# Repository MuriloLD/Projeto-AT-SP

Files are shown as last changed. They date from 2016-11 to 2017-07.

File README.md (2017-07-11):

# Projeto-AT-SP
Source code and instructions needed for constructing AntTruck and SuperTruck. Both mobile robots conected to Internet.

For more information please download the documentation [here](https://github.com/MuriloLD/Projeto-AT-SP/blob/master/Documenta%C3%A7%C3%A3o_Projeto_ATSP.pdf).

robots

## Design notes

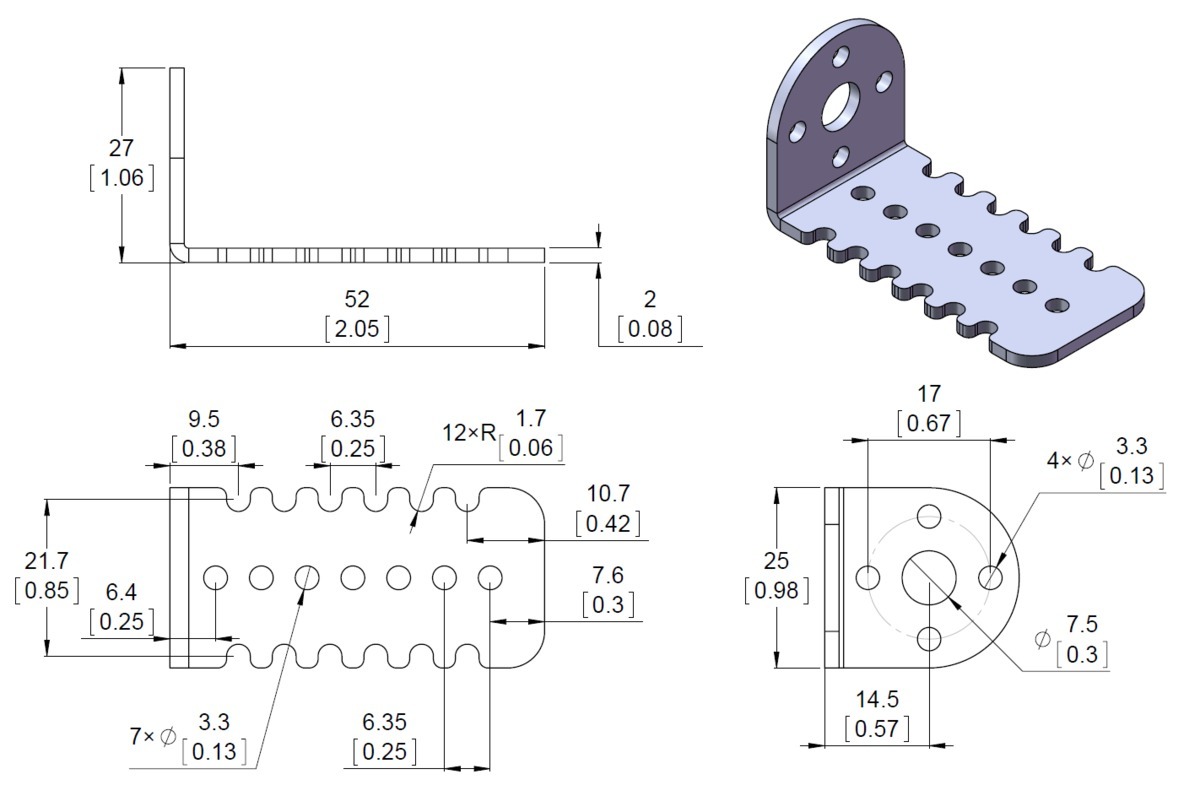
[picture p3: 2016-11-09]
Peças 3D/suporte_motor_v3/GearMotor Bracket .jpg

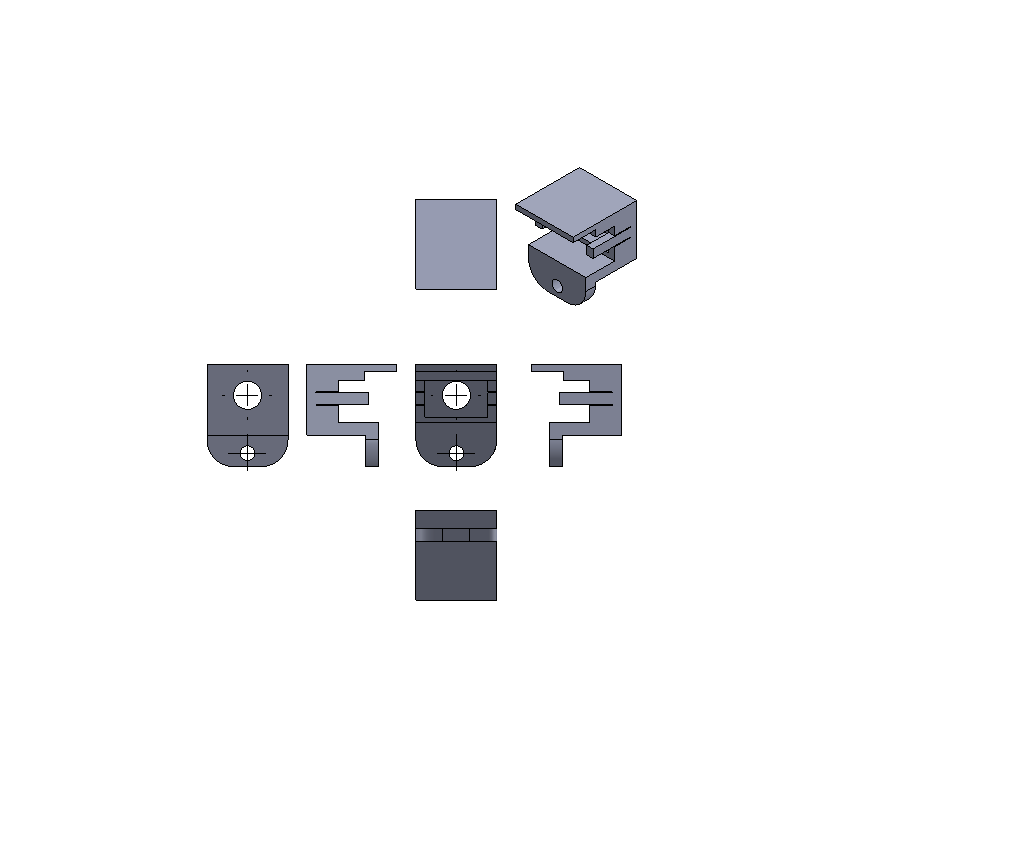
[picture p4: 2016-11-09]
Peças 3D/chave_On_Off/Top/vistas_chaveOnOff_top.PNG

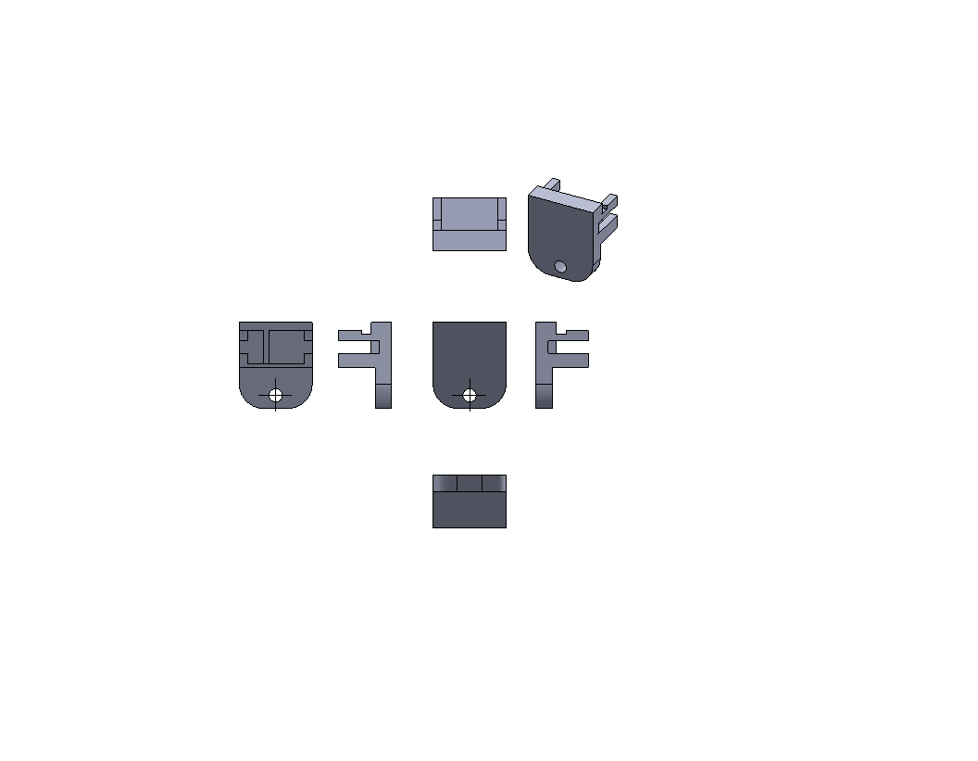
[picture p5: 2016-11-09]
Peças 3D/chave_On_Off/Bot/vistas.PNG

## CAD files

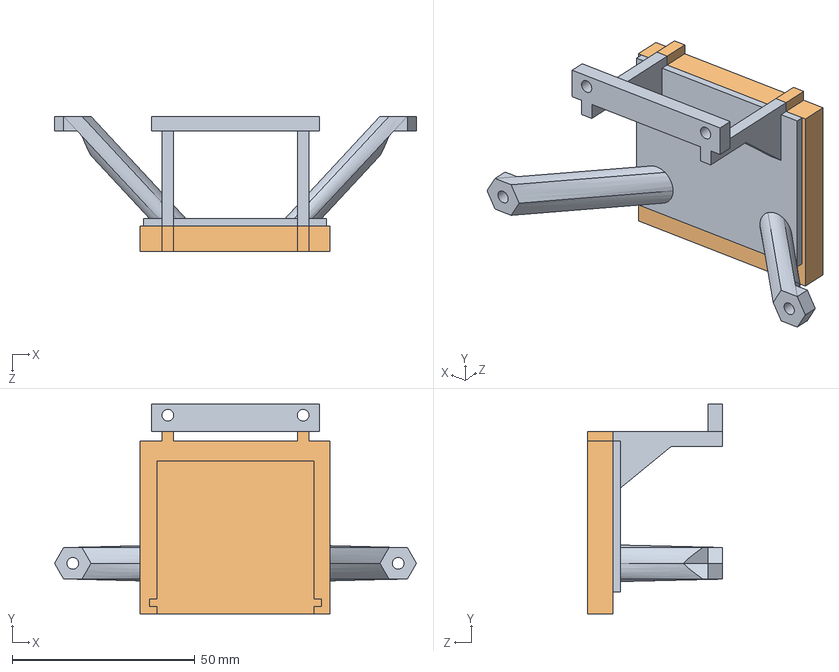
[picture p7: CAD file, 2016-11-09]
Peças 3D/suporte_ESP8266/Montagem1.SLDASM
99.0 x 57.3 x 37.0 mm
Suporte_ESP8266_v4 - P1
Suporte_ESP8266_v4 - P2

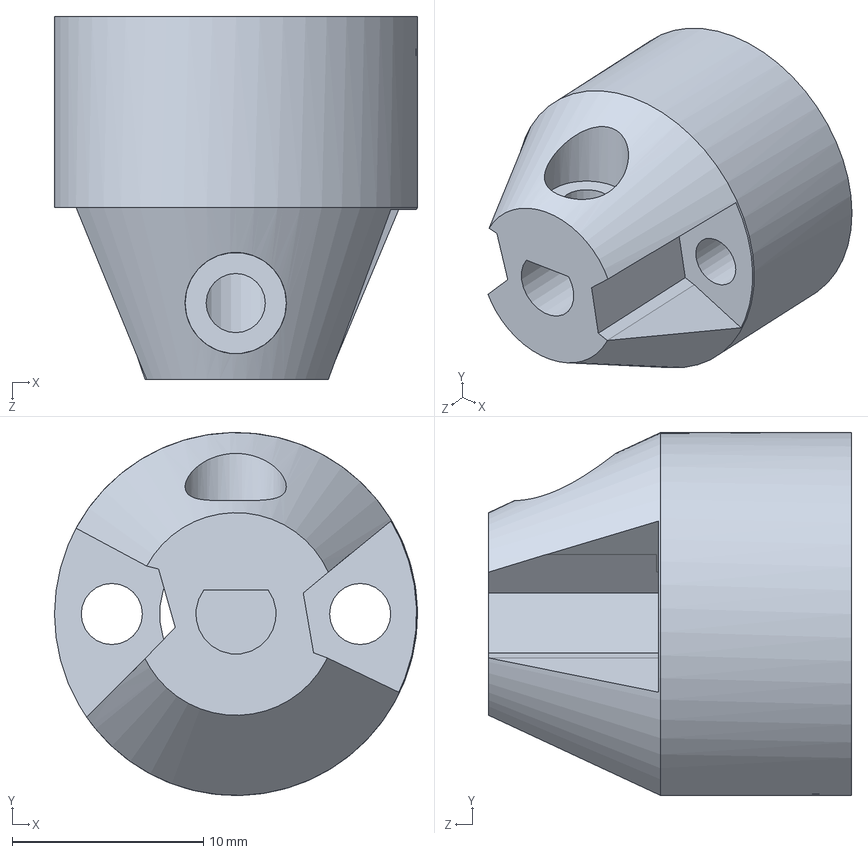
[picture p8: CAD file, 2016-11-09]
Peças 3D/adaptador_motor_v5/adaptador_motor_v5.SLDPRT
19.0 x 19.0 x 19.0 mm

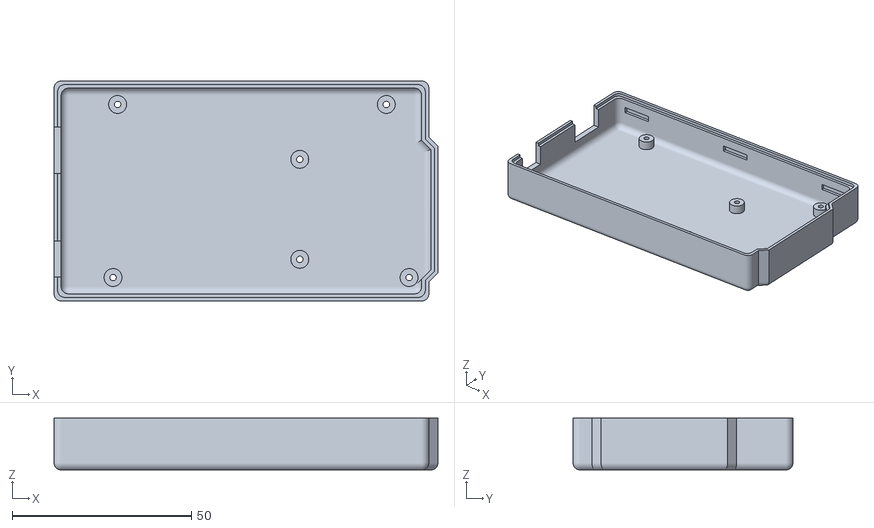
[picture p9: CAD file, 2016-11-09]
Peças 3D/case_arduino_mega_stl/arduino_mega_bottom.stl
107.1 x 61.3 x 14.5

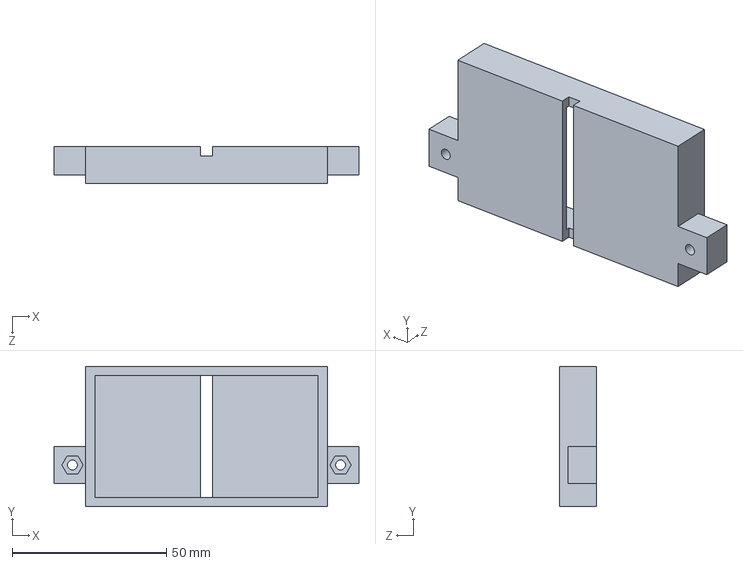
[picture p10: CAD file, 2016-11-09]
Peças 3D/case_bateria/Bot/SuporteBateria_BOT.SLDPRT
99.0 x 45.5 x 12.0 mm

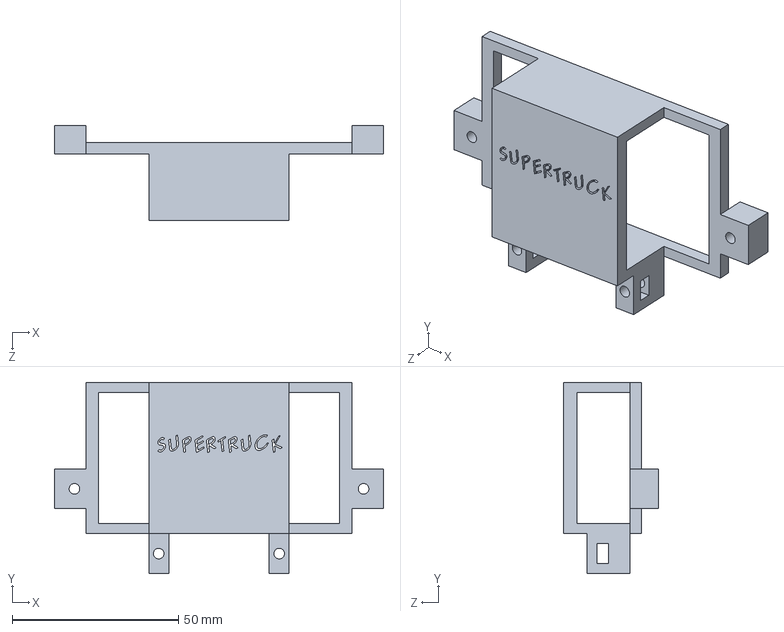
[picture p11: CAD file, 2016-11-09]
Peças 3D/case_bateria/Top/SuporteBateria_TOP.SLDPRT
99.0 x 57.5 x 28.5 mm

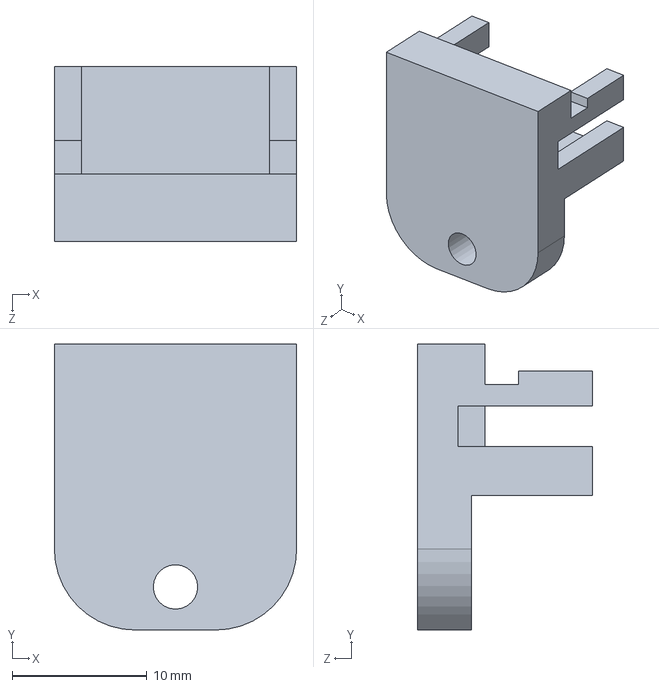
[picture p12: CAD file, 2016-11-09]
Peças 3D/chave_On_Off/Bot/Chave_v1.SLDPRT
18.0 x 21.2 x 13.0 mm

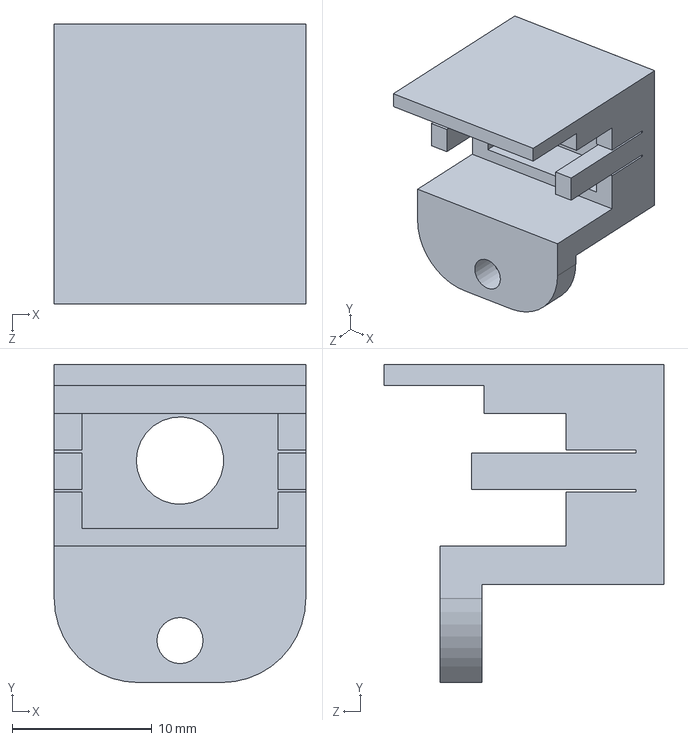
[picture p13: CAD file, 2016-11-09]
Peças 3D/chave_On_Off/Top/Chave_v2.SLDPRT
18.0 x 22.8 x 20.0 mm

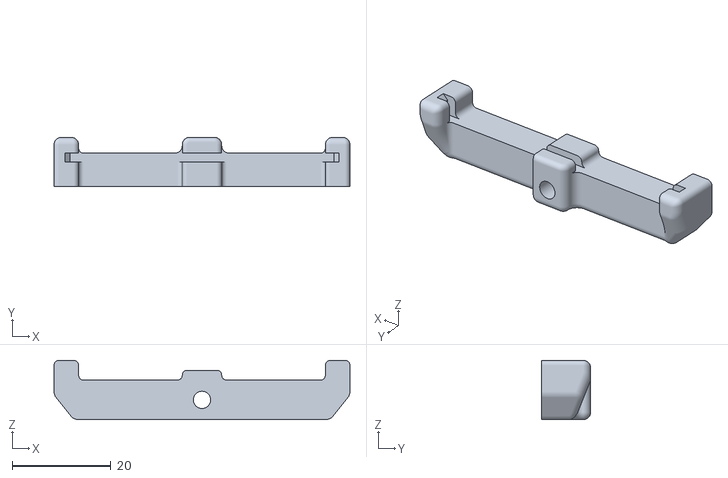
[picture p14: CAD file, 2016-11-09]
Peças 3D/suporte_arduino_mega_stl/Support carte AV Arduino.stl
60.0 x 10.0 x 12.0

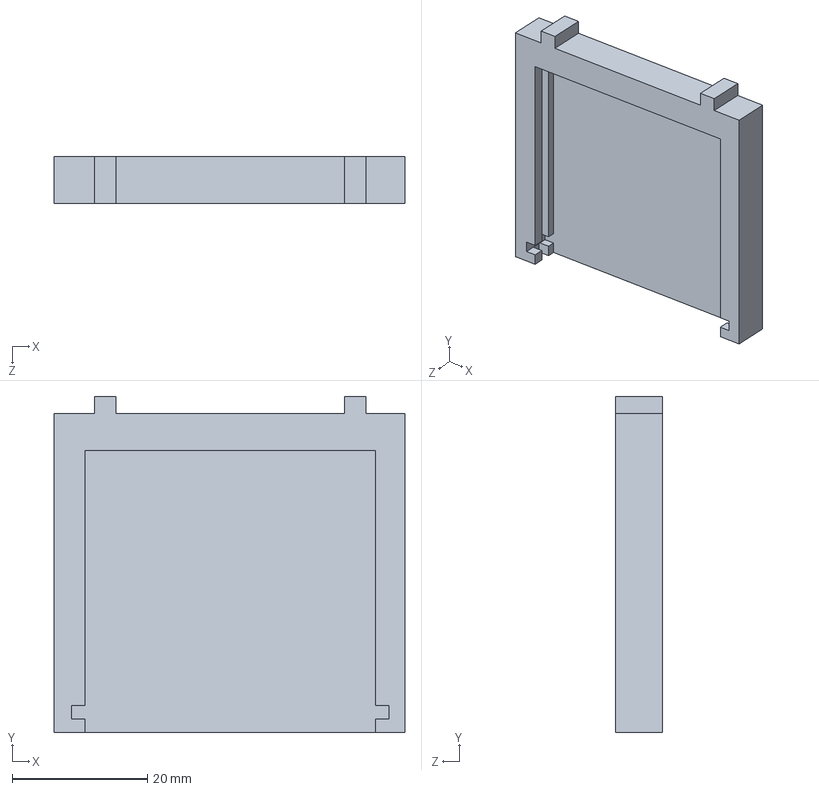
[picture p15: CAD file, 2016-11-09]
Peças 3D/suporte_ESP8266/Suporte_ESP8266_v4 - P2.SLDPRT
52.0 x 49.8 x 7.00 mm

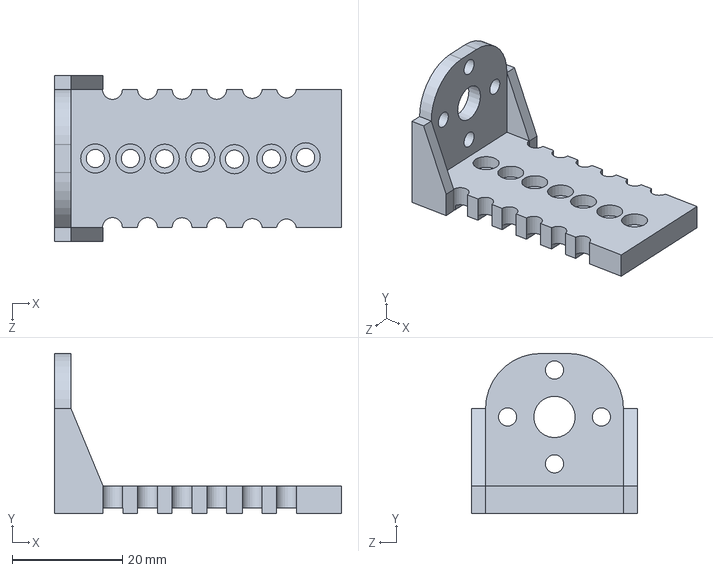
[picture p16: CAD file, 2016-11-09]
Peças 3D/suporte_motor_v3/suporte motor_v3.SLDPRT
52.0 x 29.0 x 30.0 mm

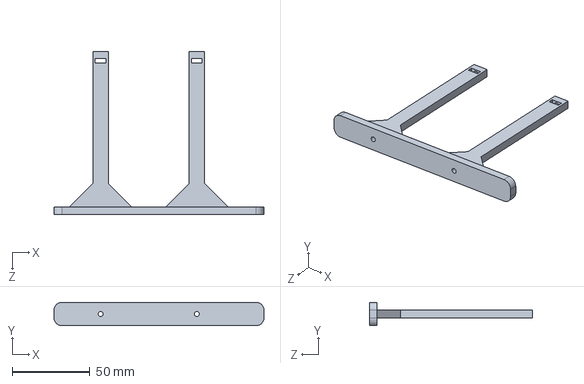
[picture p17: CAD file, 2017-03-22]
Peças 3D/suporte_padrao/suporte_padrao.SLDPRT
135.0 x 15.0 x 105.0 mm

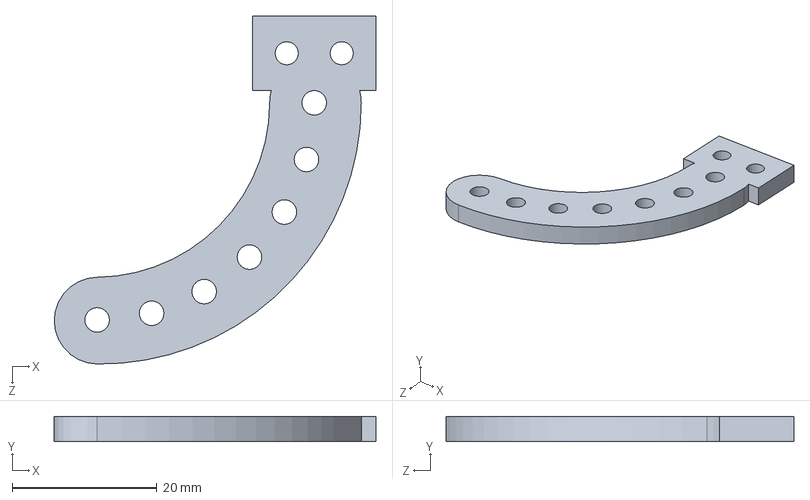
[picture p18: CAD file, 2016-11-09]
Peças 3D/suporte_ultrassom/US_guia/us_guia.SLDPRT
44.4 x 3.50 x 48.1 mm

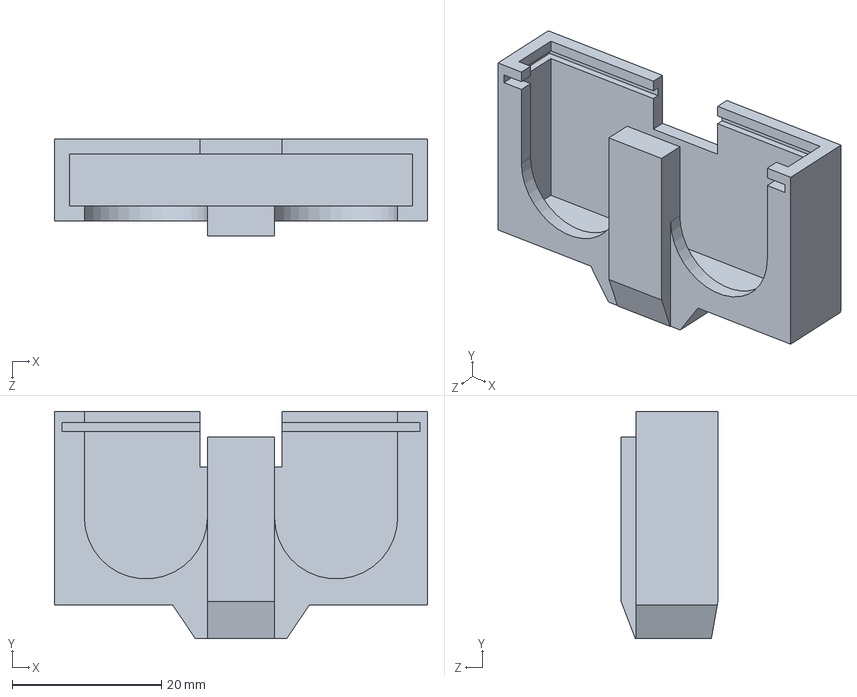
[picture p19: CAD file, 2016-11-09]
Peças 3D/suporte_ultrassom/US_Servo/ultrassom - SERVO.SLDPRT
50.0 x 30.4 x 13.0 mm

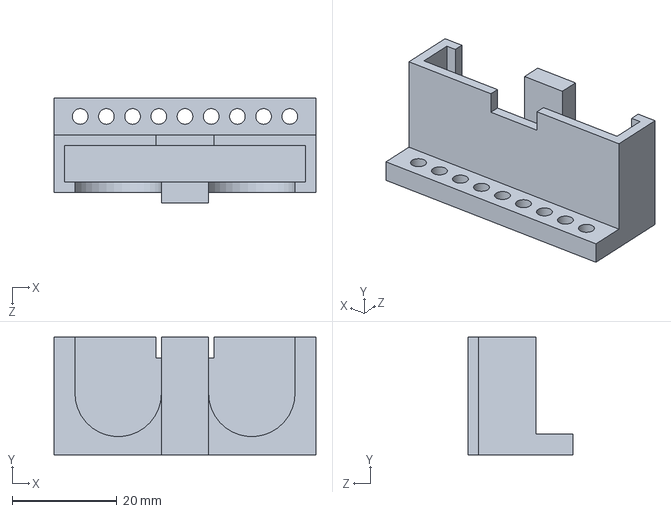
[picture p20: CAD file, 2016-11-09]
Peças 3D/suporte_ultrassom/US_simples/ultrassom.SLDPRT
50.0 x 22.5 x 20.0 mm

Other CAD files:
Peças 3D/case_arduino_mega_stl/arduino_mega_top.stl
Peças 3D/suporte_arduino_mega_stl/Support carte AR Arduino.stl
Peças 3D/suporte_ESP8266/Suporte_ESP8266_v4 - P3.SLDPRT
Peças 3D/suporte_ESP8266/Montagem1 - Suporte_ESP8266_v4 - P2-1.STL
Peças 3D/adaptador_motor_v5/Template_cotas.SLDDRW
Peças 3D/adaptador_motor_v5/adaptador_motor_v5.STL
Peças 3D/adaptador_motor_v5/template_vistas.SLDDRW
Peças 3D/case_bateria/Bot/SuporteBateria_BOT.STL
Peças 3D/case_bateria/Bot/Template_cotas.SLDDRW
Peças 3D/case_bateria/Bot/template_vistas.SLDDRW
Peças 3D/case_bateria/Top/SuporteBateria_TOP.STL
Peças 3D/case_bateria/Top/Template_cotas.SLDDRW
Peças 3D/case_bateria/Top/template_vistas.SLDDRW
Peças 3D/chave_On_Off/Bot/Chave_v1.STL
Peças 3D/chave_On_Off/Bot/Template_cotas.SLDDRW
Peças 3D/chave_On_Off/Bot/template_vistas.SLDDRW
Peças 3D/chave_On_Off/Top/Chave_v2.STL
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

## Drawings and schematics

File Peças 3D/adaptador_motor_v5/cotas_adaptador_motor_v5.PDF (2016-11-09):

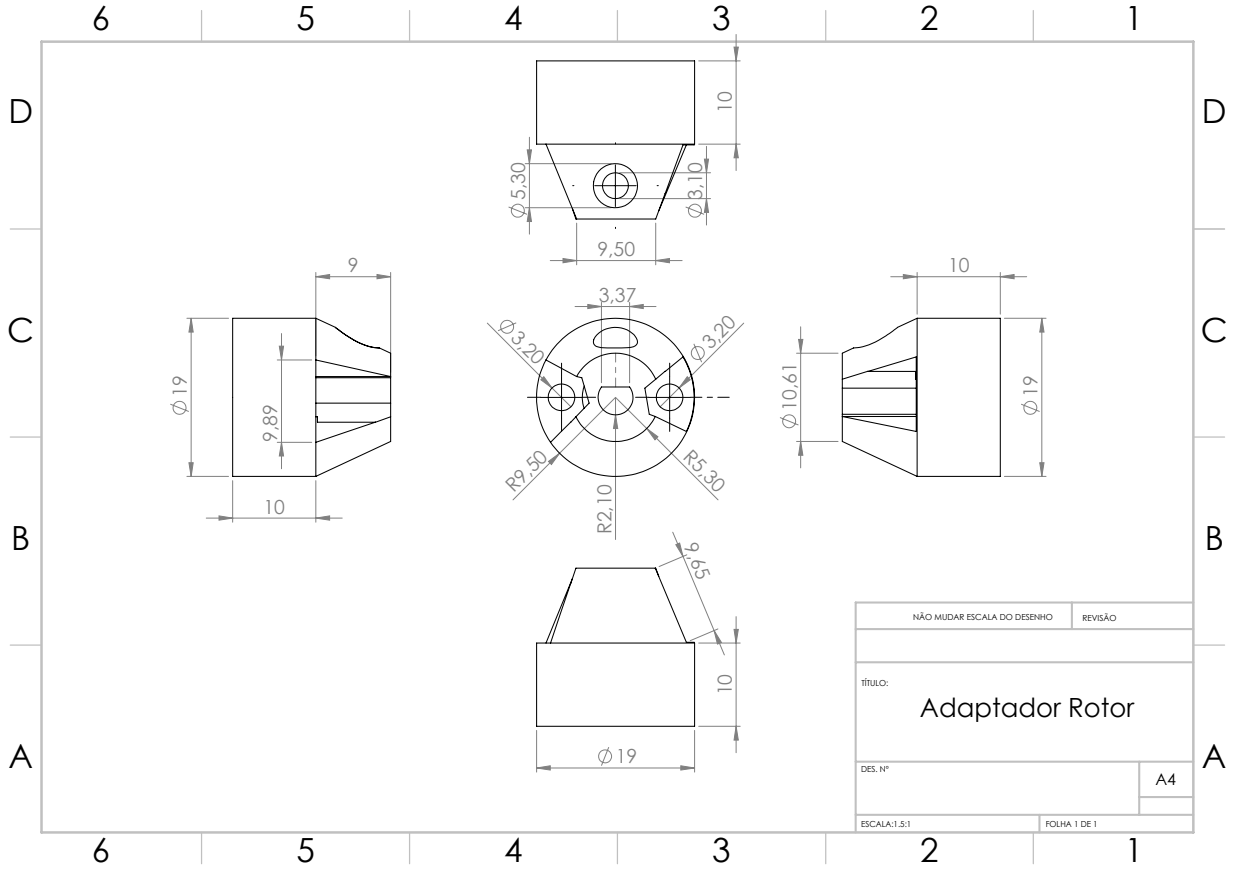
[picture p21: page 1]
NÃO MUDAR ESCALA DO DESENHO; REVISÃO; DES. Nº; ESCALA:1.5:1; FOLHA 1 DE 1; Adaptador Rotor

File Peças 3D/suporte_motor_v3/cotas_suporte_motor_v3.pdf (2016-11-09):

D

6 | 5 | 4 | 3 | 2 | 1

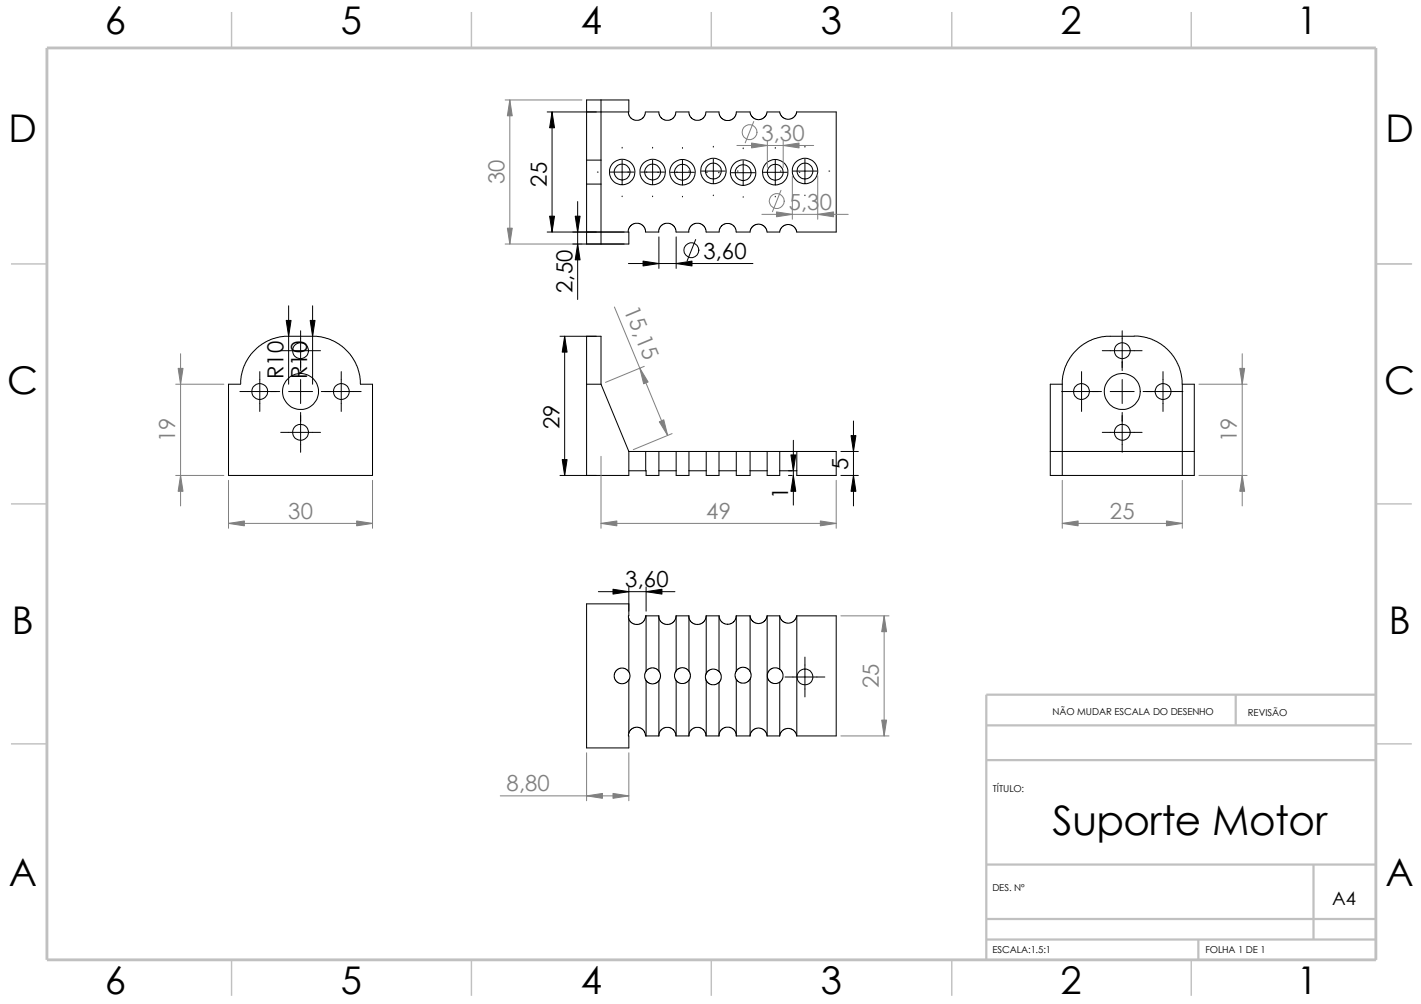
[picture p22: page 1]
NÃO MUDAR ESCALA DO DESENHO; REVISÃO; TÍTULO:; DES. Nº; ESCALA:1.5:1; FOLHA 1 DE 1; Suporte Motor

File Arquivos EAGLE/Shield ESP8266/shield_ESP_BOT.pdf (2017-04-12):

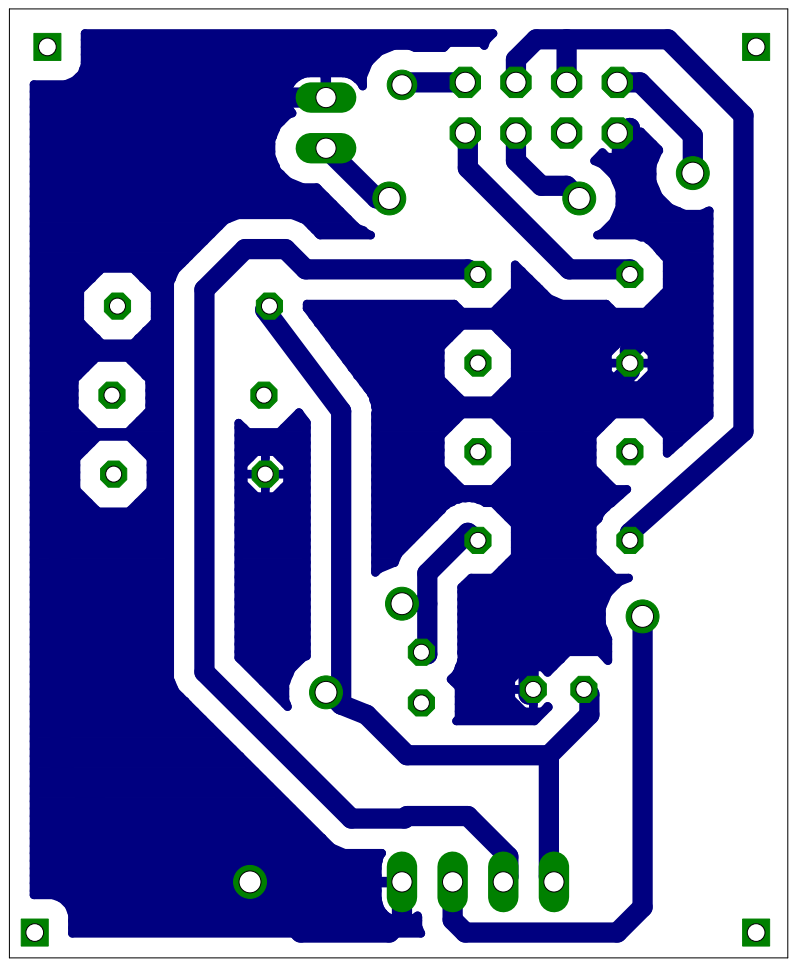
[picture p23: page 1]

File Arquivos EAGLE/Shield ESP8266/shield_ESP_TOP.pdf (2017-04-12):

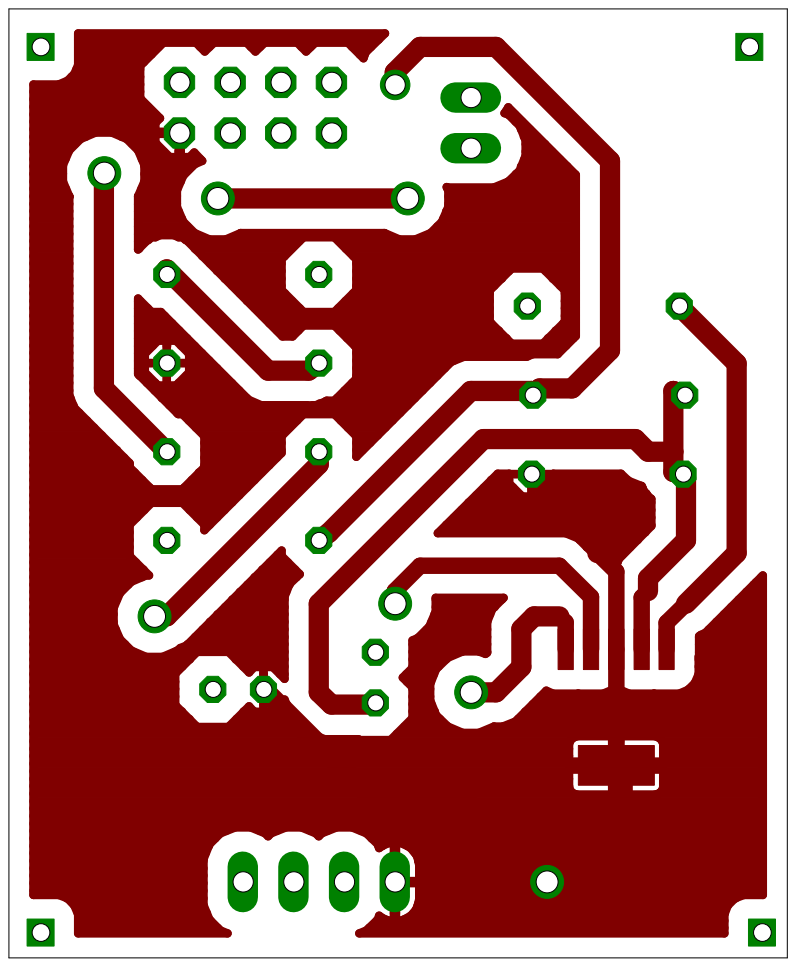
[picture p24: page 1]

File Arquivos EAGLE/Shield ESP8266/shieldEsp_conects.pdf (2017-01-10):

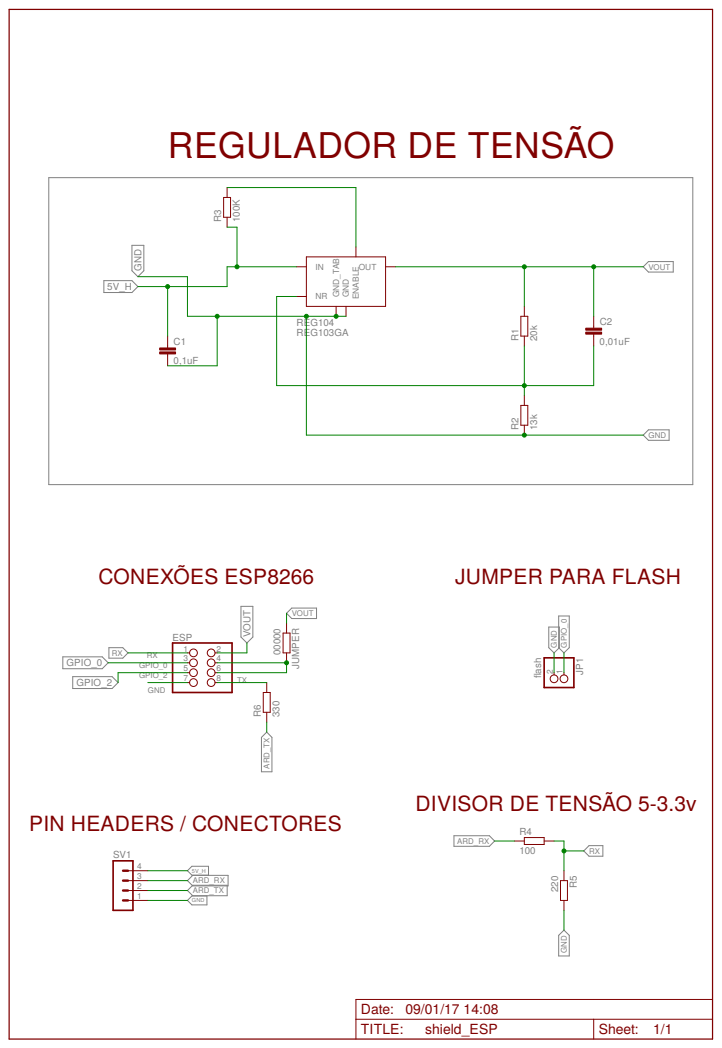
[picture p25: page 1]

5 6
7 8 | TX

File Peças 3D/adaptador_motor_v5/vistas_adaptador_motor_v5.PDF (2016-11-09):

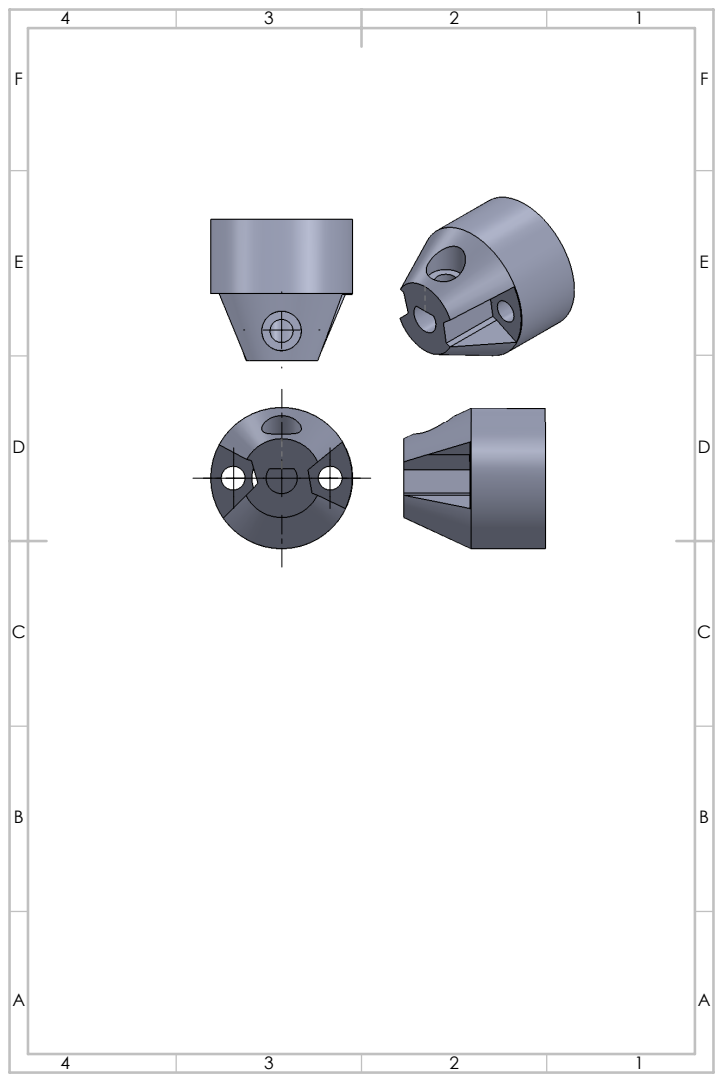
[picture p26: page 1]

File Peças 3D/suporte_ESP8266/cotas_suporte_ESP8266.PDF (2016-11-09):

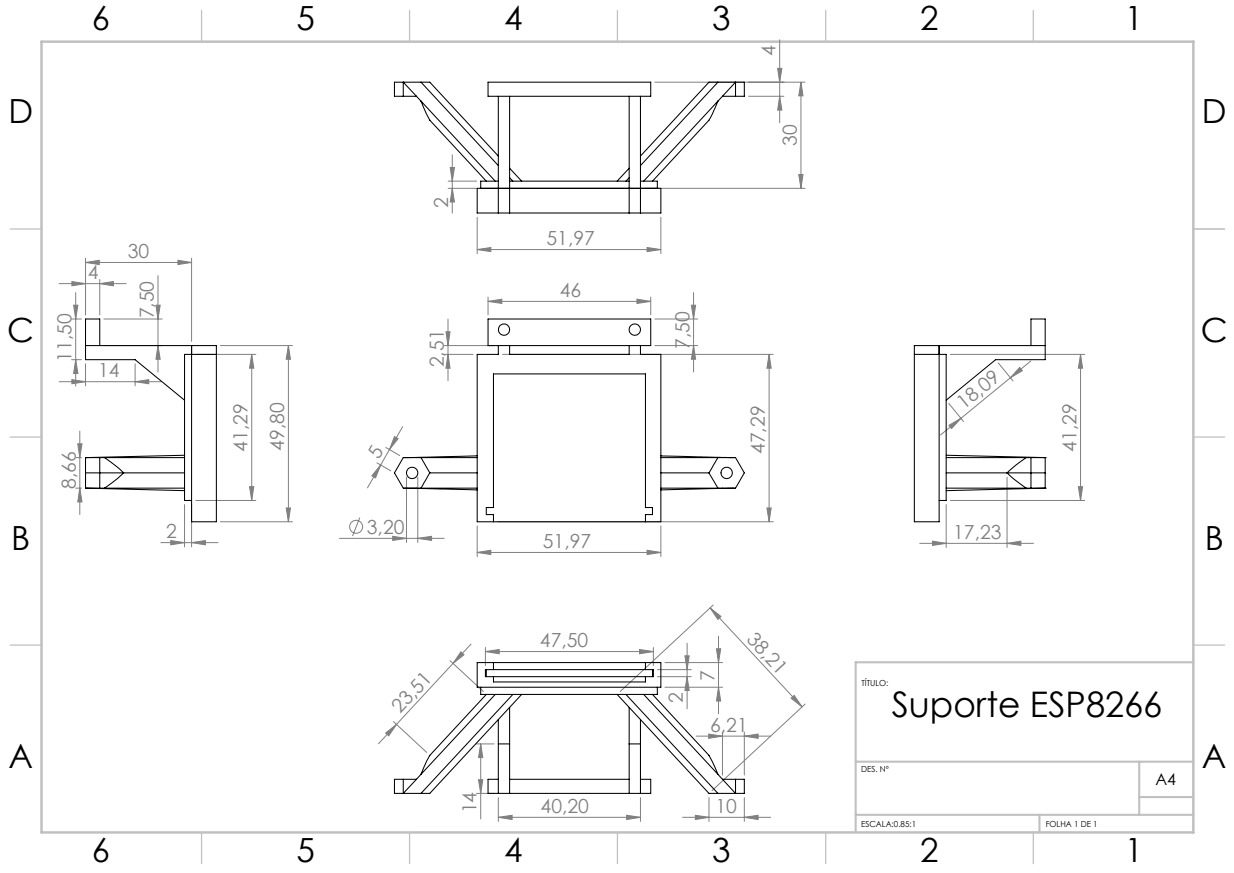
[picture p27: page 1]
DES. Nº; ESCALA:0.85:1; FOLHA 1 DE 1; Suporte ESP8266

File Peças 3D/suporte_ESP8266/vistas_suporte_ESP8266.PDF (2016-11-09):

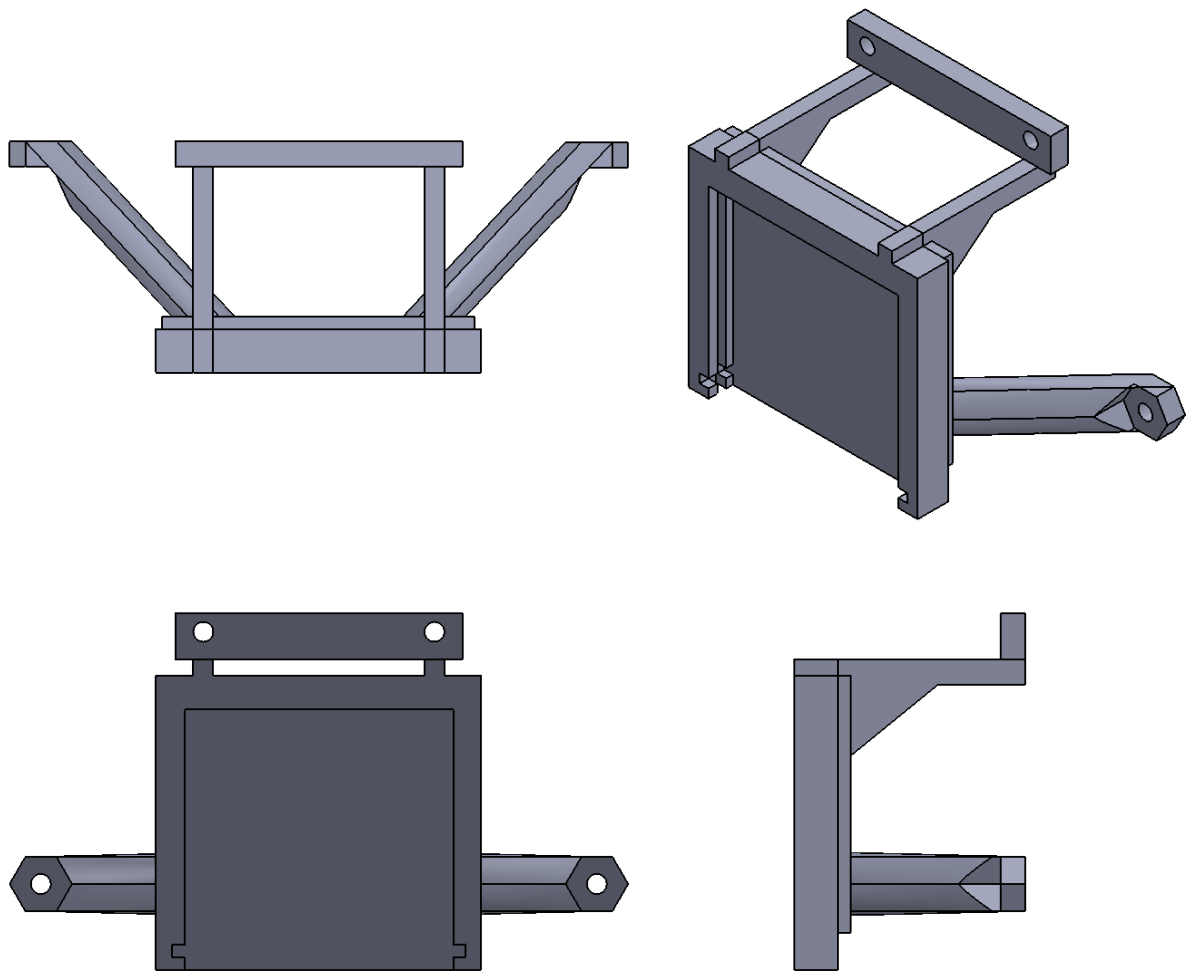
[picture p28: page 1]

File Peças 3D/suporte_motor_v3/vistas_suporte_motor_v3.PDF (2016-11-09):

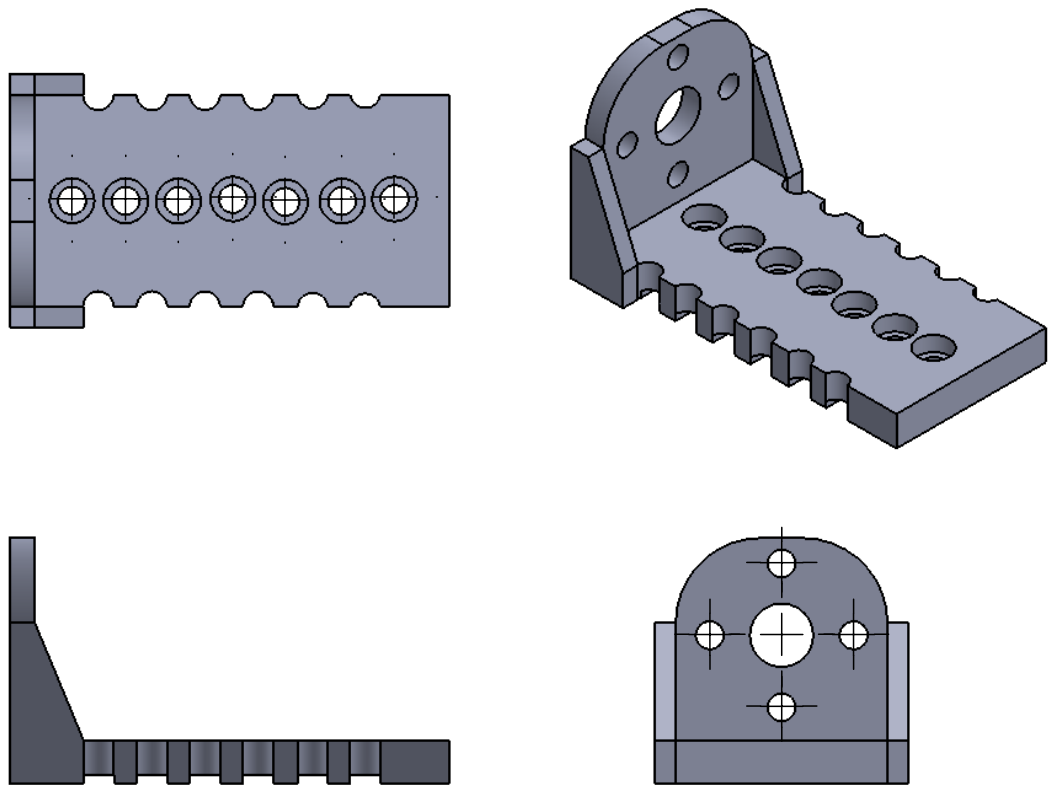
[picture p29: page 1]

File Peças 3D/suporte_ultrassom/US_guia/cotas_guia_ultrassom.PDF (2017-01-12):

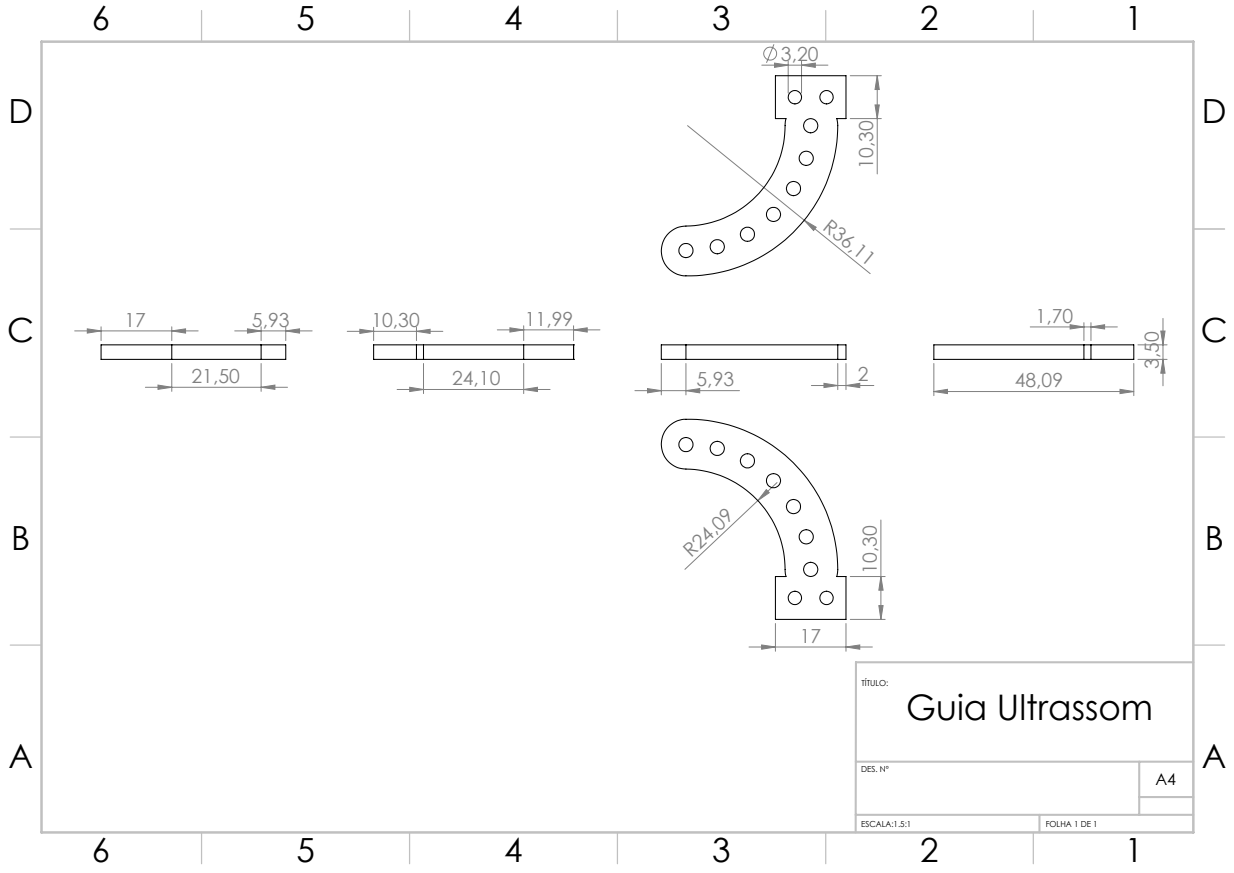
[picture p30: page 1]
DES. Nº; ESCALA:1.5:1; FOLHA 1 DE 1; Guia Ultrassom

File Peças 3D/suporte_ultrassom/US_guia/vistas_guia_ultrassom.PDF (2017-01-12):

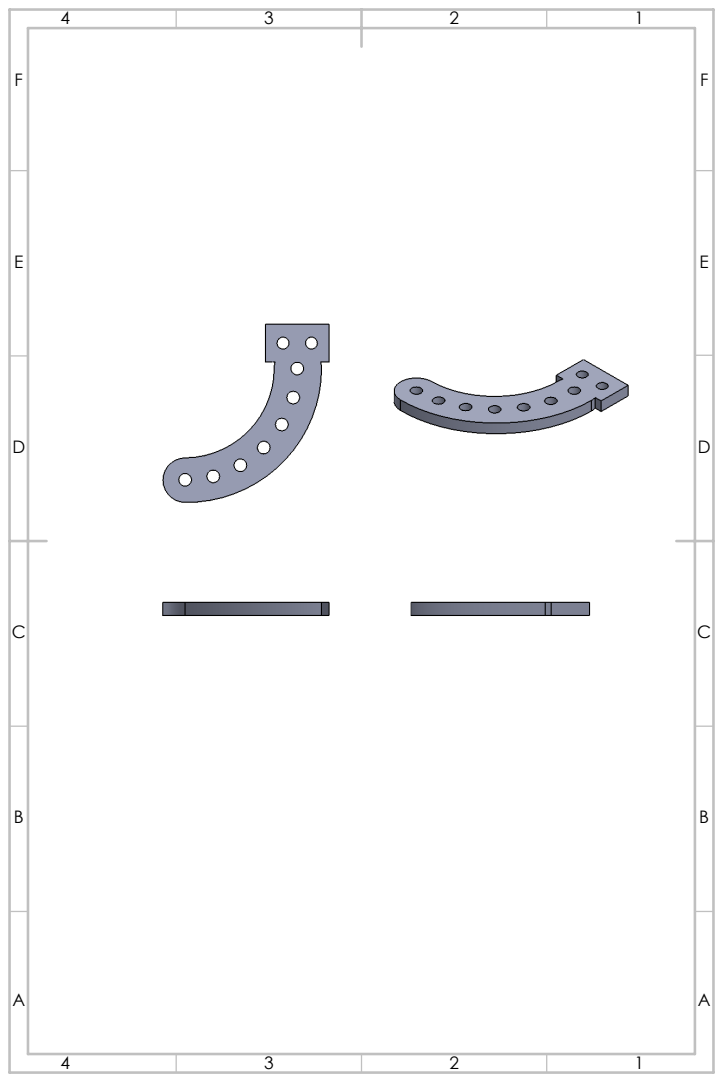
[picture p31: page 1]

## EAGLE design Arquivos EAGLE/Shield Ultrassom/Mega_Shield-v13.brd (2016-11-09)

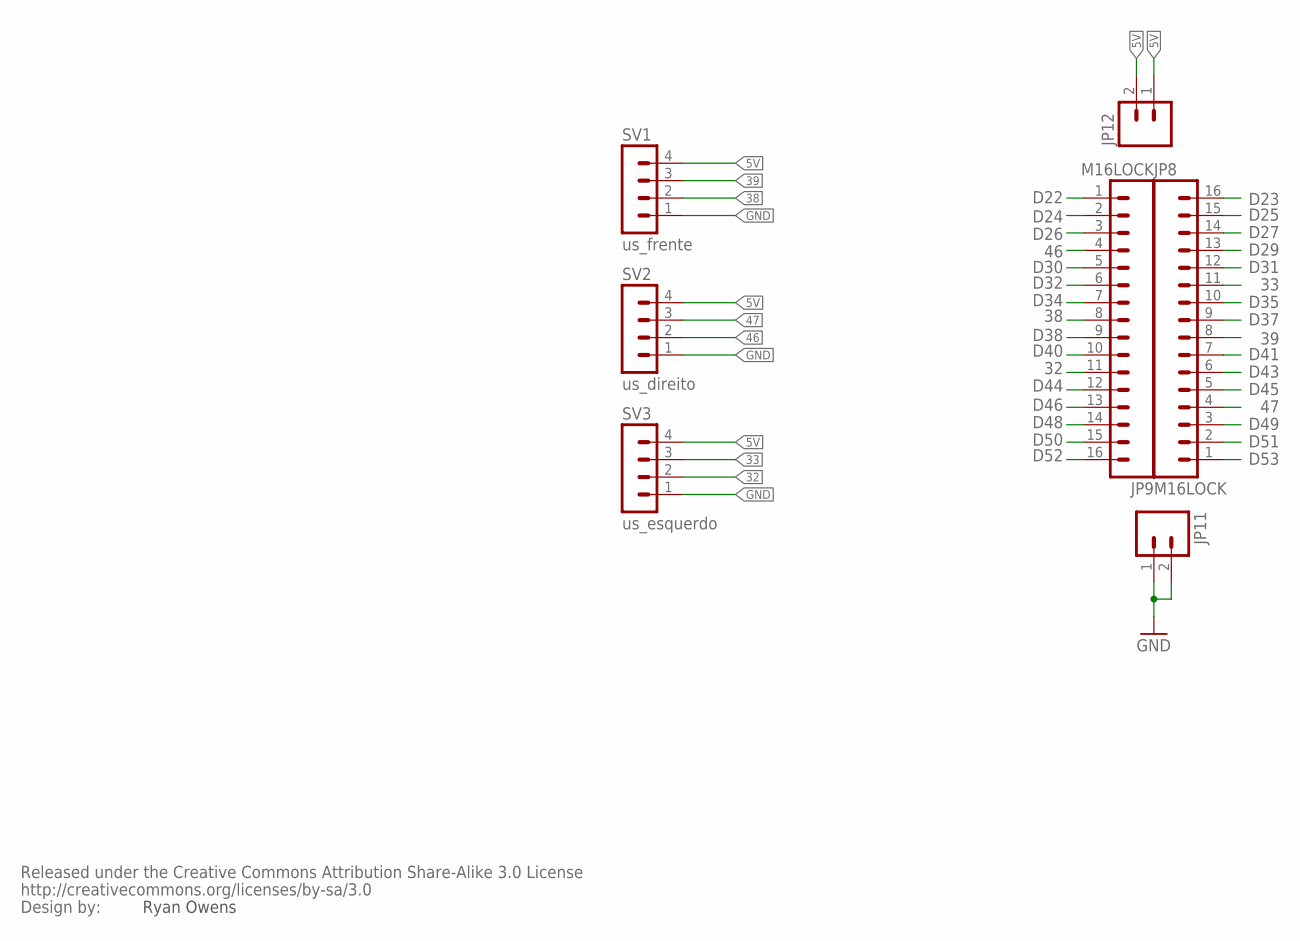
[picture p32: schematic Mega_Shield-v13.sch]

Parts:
JP8, JP9: M16LOCK; 1X16_LOCK
JP11, JP12: M02LOCK; 1X02_LOCK
SV1: us_frente; MA04-1
SV2: us_direito; MA04-1
SV3: us_esquerdo; MA04-1
U$2: CREATIVE_COMMONS

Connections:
5V: JP12.1, JP12.2, SV1.4, SV2.4, SV3.4
32: JP9.11, SV3.2
33: JP8.11, SV3.3
38: JP9.8, SV1.2
39: JP8.8, SV1.3
46: JP9.4, SV2.2
47: JP8.4, SV2.3
D22: JP9.1
D23: JP8.16
D24: JP9.2
D25: JP8.15
D26: JP9.3
D27: JP8.14
D29: JP8.13
D30: JP9.5
D31: JP8.12
D32: JP9.6
D34: JP9.7
D35: JP8.10
D37: JP8.9
D38: JP9.9
D40: JP9.10
D41: JP8.7
D43: JP8.6
D44: JP9.12
D45: JP8.5
D46: JP9.13
D48: JP9.14
D49: JP8.3
D50: JP9.15
D51: JP8.2
D52: JP9.16
D53: JP8.1
GND: JP11.1, JP11.2, SV1.1, SV2.1, SV3.1

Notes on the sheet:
Ryan Owens

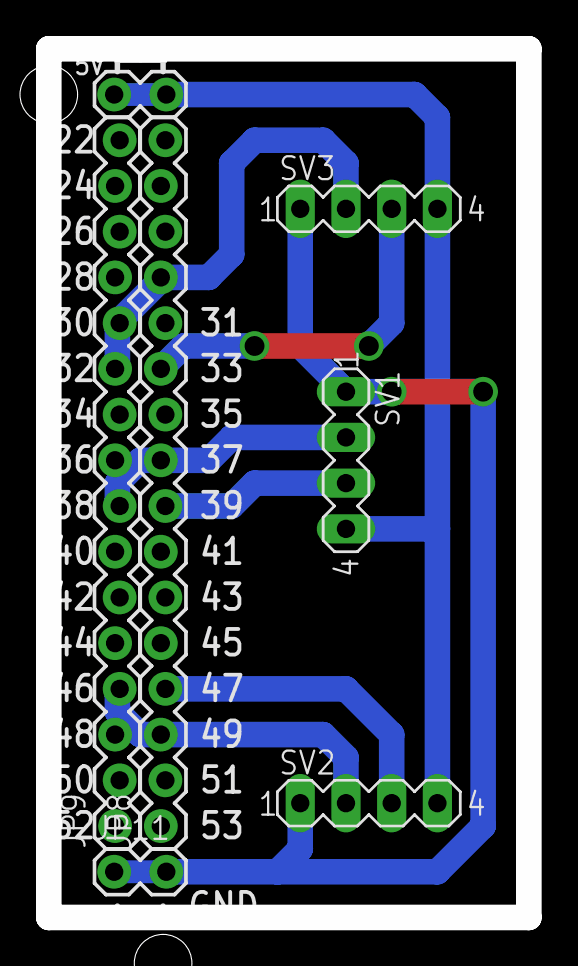
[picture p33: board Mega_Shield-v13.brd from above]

Board: 2 copper layers, 26.7 x 48.3 mm, 8 parts (0 on the bottom side), 8 nets.

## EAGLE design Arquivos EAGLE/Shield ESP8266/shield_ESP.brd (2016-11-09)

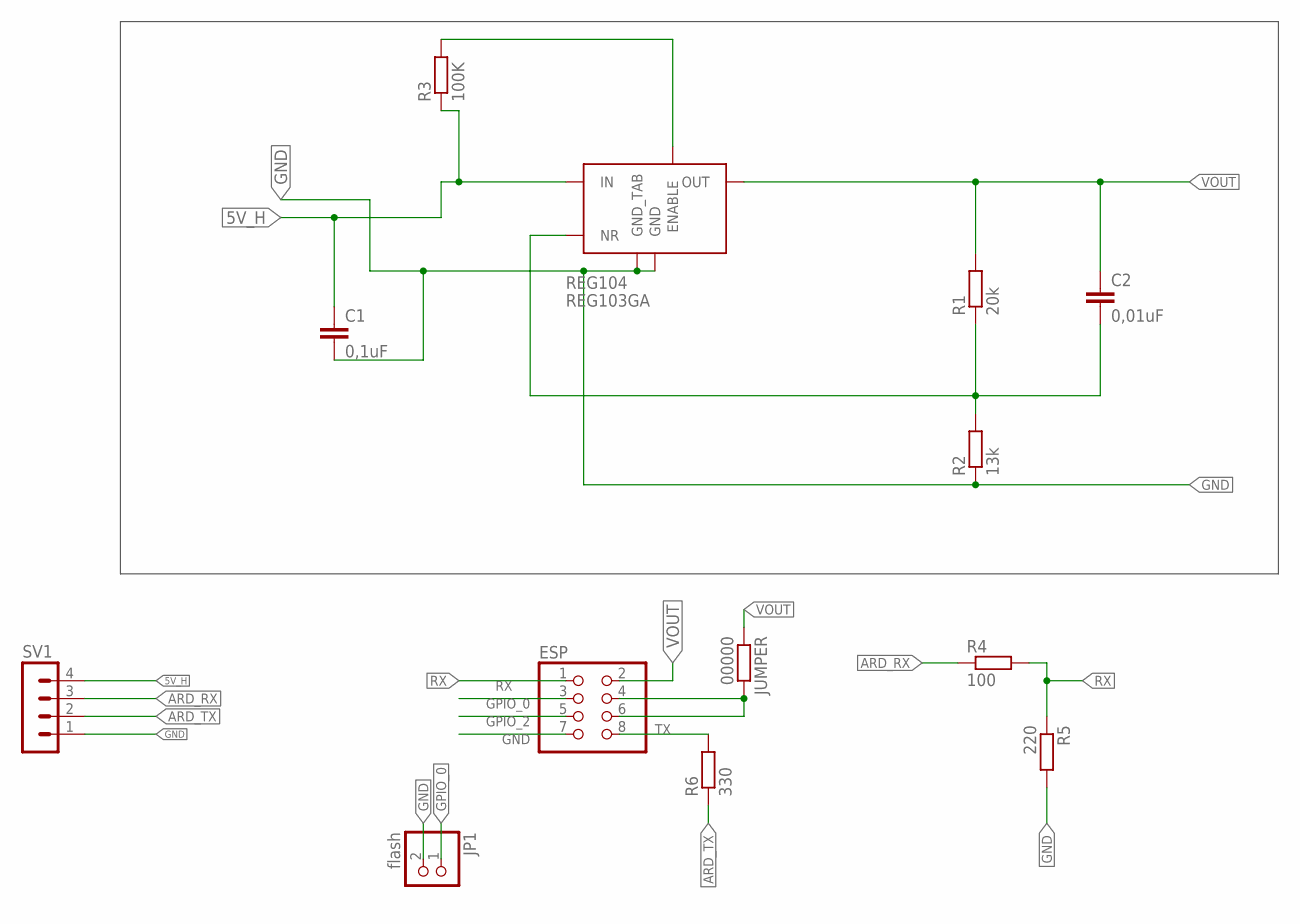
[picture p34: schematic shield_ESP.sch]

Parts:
C1: 0,1uF; C025-025X050
C2: 0,01uF; C025-025X050
ESP: PINHD-2X4; 2X04
JP1: flash; 1X02/90
JUMPER: 00000; 0207/7
R1: 20k; 0207/7
R2: 13k; 0207/7
R3: 100K; 0207/7
R4: 100; 0207/7
R5: 220; 0207/7
R6: 330; 0207/7
REG104: REG103GA; SOT223-5
SV1: MA04-1

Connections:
5V_H: C1.1, R3.1, REG104.1 (IN), SV1.4
ARD_RX: R4.1, SV1.3
ARD_TX: R6.1, SV1.2
GND: C1.2, ESP.7, JP1.2, R2.1, R5.2, REG104.3 (GND), REG104.TAB (GND_TAB), SV1.1
GPIO_0: ESP.3, JP1.1
GPIO_2: ESP.5
unnamed: ESP.4, ESP.6, JUMPER.2
unnamed: C2.2, R1.1, R2.2, REG104.4 (NR)
unnamed: R3.2, REG104.5 (ENABLE)
RX: ESP.1, R4.2, R5.1
TX: ESP.8, R6.2
VOUT: C2.1, ESP.2, JUMPER.1, R1.2, REG104.2 (OUT)

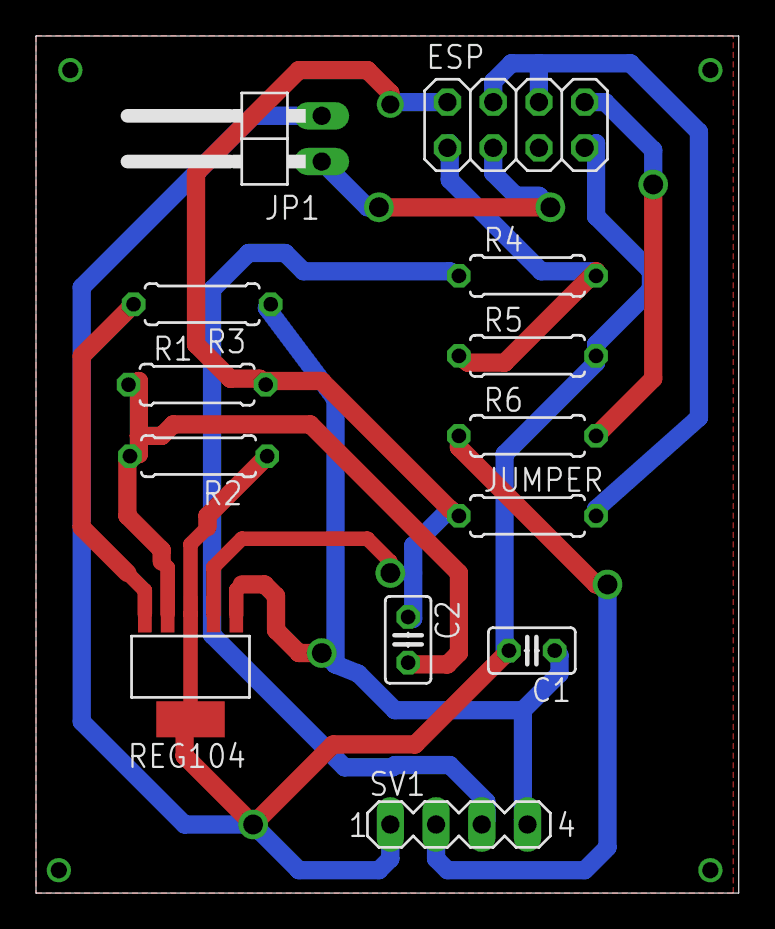
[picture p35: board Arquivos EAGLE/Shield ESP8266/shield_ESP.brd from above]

Board: 2 copper layers, 39.0 x 47.6 mm, 13 parts (0 on the bottom side), 11 nets.

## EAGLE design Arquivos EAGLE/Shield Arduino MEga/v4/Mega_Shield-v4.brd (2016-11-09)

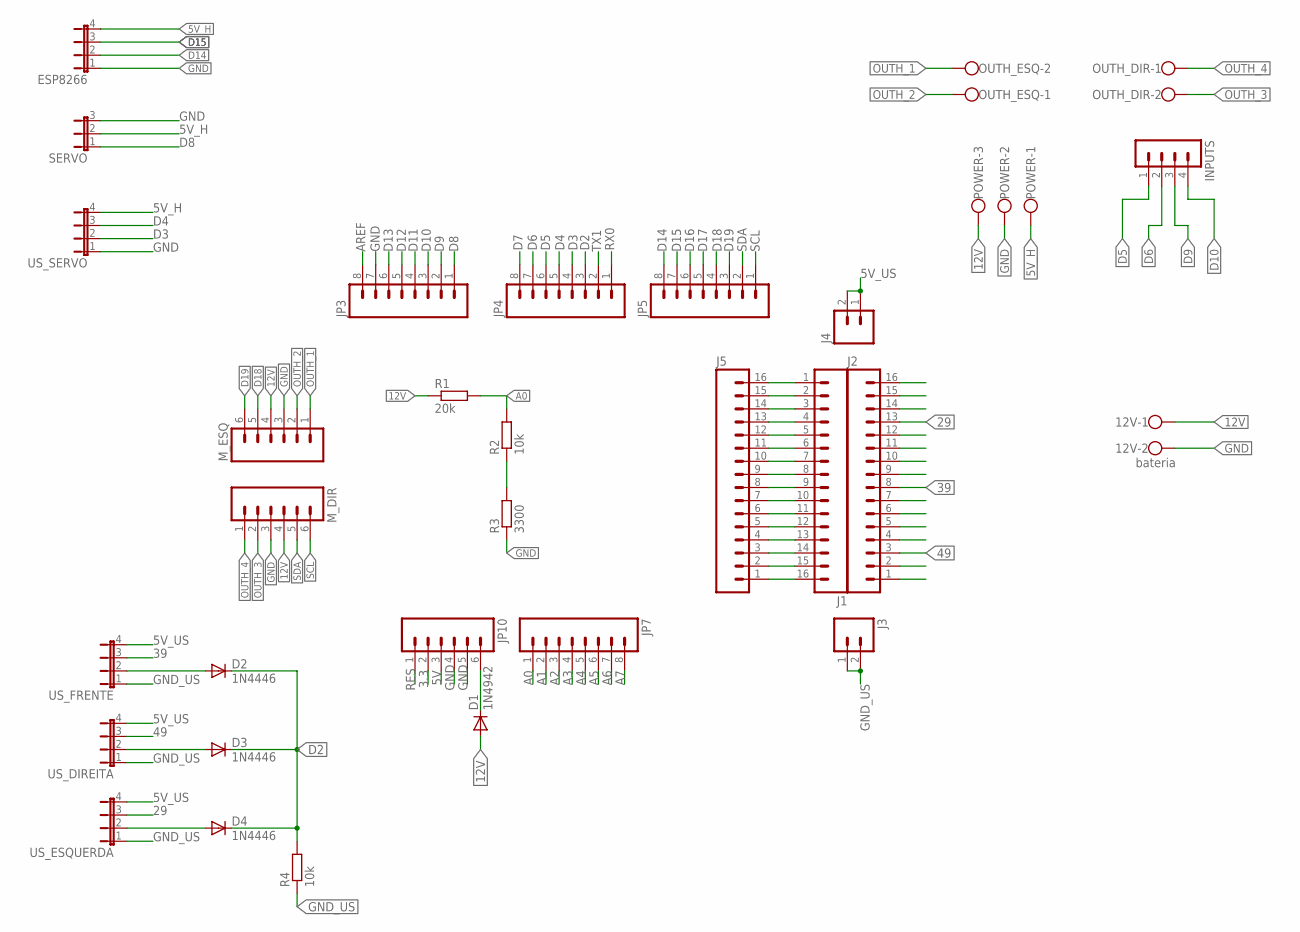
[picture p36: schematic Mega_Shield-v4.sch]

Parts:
12V: bateria; W237-102
D1: 1N4942; DO41-10
D2, D3, D4: 1N4446; DO35-10
ESP8266: JP4E; JP4
INPUTS: MA04-1
J1, J2, J5: M16LOCK; 1X16_LOCK
J3, J4: M02LOCK; 1X02_LOCK
JP3, JP4, JP5, JP7: M08LOCK; 1X08_LOCK
JP10: M06LOCK; 1X06_LOCK
M_DIR: M06LOCK; 1X06_LOCK
M_ESQ: M06LOCK; 1X06_LOCK
OUTH_DIR: W237-102
OUTH_ESQ: W237-102
POWER: W237-103
R1: 20k; 0207/10
R2, R4: 10k; 0207/10
R3: 3300; 0207/10
SERVO: JP2W
US_DIREITA: JP4E; JP4
US_ESQUERDA: JP4E; JP4
US_FRENTE: JP4E; JP4
US_SERVO: JP4E; JP4

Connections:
3.3: JP10.2
5V: JP10.3
5V_H: ESP8266.4, POWER.1, SERVO.2, US_SERVO.4
5V_US: J4.1, J4.2, US_DIREITA.4, US_ESQUERDA.4, US_FRENTE.4
12V: 12V.1, D1.A, M_DIR.4, M_ESQ.4, POWER.3, R1.1
29: J2.13, US_ESQUERDA.3
39: J2.8, US_FRENTE.3
49: J2.3, US_DIREITA.3
A0: JP7.1, R1.2, R2.2
A1: JP7.2
A2: JP7.3
A3: JP7.4
A4: JP7.5
A5: JP7.6
A6: JP7.7
A7: JP7.8
AREF: JP3.8
D2: D2.C, D3.C, D4.C, JP4.3, R4.2
D3: JP4.4, US_SERVO.2
D4: JP4.5, US_SERVO.3
D5: INPUTS.1, JP4.6
D6: INPUTS.2, JP4.7
D7: JP4.8
D8: JP3.1, SERVO.1
D9: INPUTS.3, JP3.2
D10: INPUTS.4, JP3.3
D11: JP3.4
D12: JP3.5
D13: JP3.6
D14: ESP8266.2, JP5.8
D15: ESP8266.3, JP5.7
D16: JP5.6
D17: JP5.5
D18: JP5.4, M_ESQ.5
D19: JP5.3, M_ESQ.6
GND: 12V.2, ESP8266.1, JP3.7, JP10.4, JP10.5, M_DIR.3, M_ESQ.3, POWER.2, R3.1, SERVO.3, US_SERVO.1
GND_US: J3.1, J3.2, R4.1, US_DIREITA.1, US_ESQUERDA.1, US_FRENTE.1
unnamed: R2.1, R3.2
unnamed: D1.C, JP10.6
unnamed: D2.A, US_FRENTE.2
unnamed: J1.16, J5.1
unnamed: D3.A, US_DIREITA.2
unnamed: J1.15, J5.2
unnamed: J1.14, J5.3
unnamed: J1.13, J5.4
unnamed: D4.A, US_ESQUERDA.2
unnamed: J1.12, J5.5
unnamed: J1.11, J5.6
unnamed: J1.10, J5.7
unnamed: J1.9, J5.8
unnamed: J1.8, J5.9
unnamed: J1.7, J5.10
unnamed: J1.6, J5.11
unnamed: J1.5, J5.12
unnamed: J1.4, J5.13
unnamed: J1.3, J5.14
unnamed: J1.2, J5.15
unnamed: J1.1, J5.16
OUTH_1: M_ESQ.1, OUTH_ESQ.2
OUTH_2: M_ESQ.2, OUTH_ESQ.1
OUTH_3: M_DIR.2, OUTH_DIR.2
OUTH_4: M_DIR.1, OUTH_DIR.1
RES: JP10.1
RX0: JP4.1
SCL: JP5.1, M_DIR.6
SDA: JP5.2, M_DIR.5
TX1: JP4.2

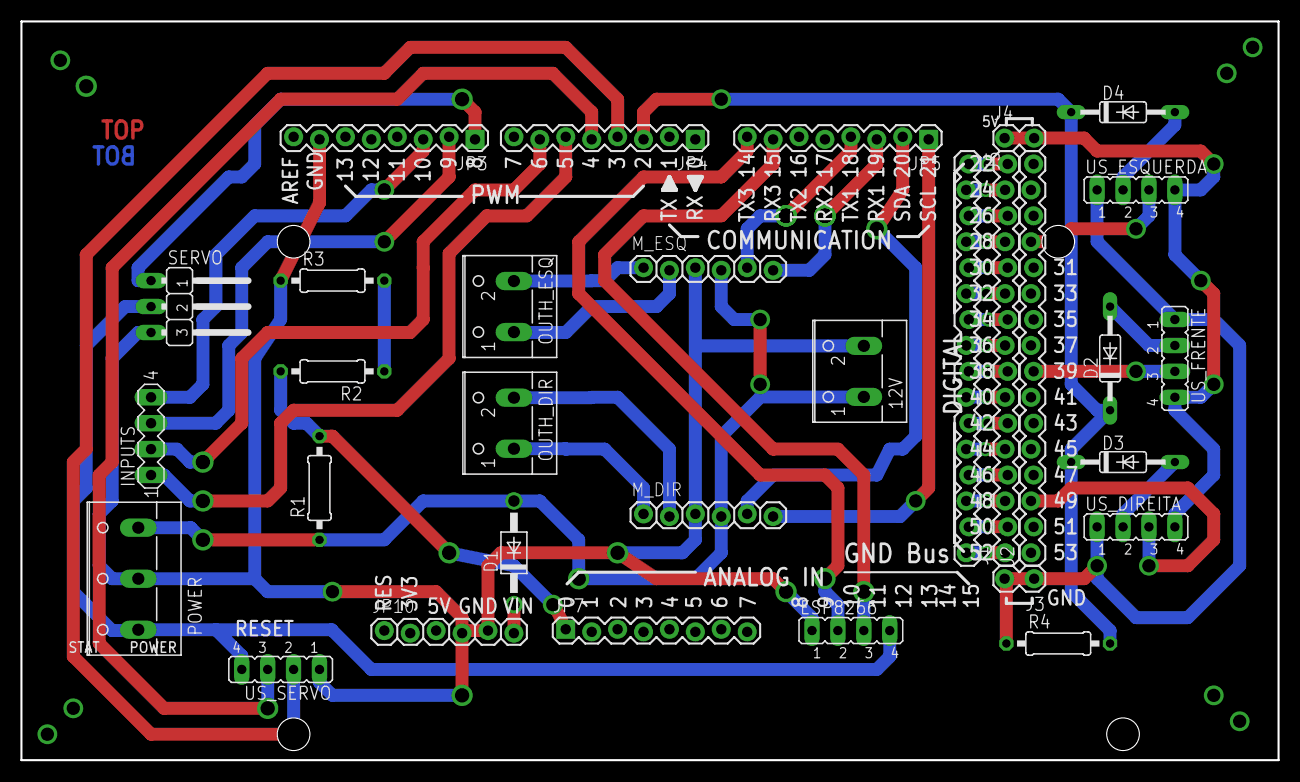
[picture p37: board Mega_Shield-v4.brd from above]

Board: 2 copper layers, 123.2 x 72.4 mm, 31 parts (0 on the bottom side), 48 nets.

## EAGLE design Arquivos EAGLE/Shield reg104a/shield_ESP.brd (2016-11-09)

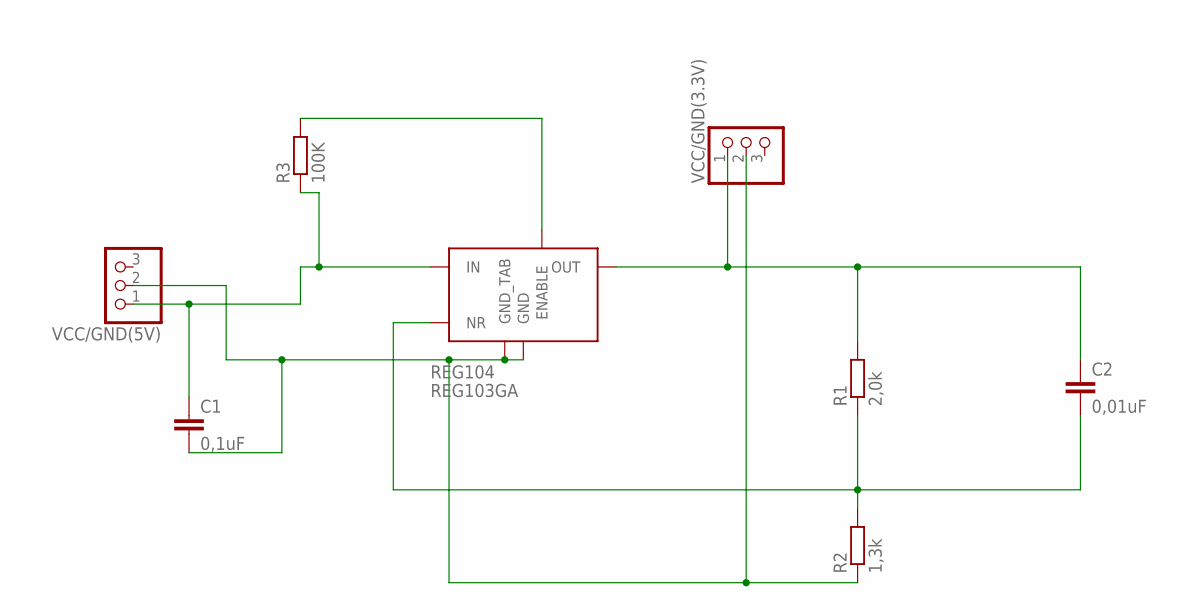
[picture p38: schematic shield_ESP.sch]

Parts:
C1: 0,1uF; C025-025X050
C2: 0,01uF; C025-025X050
R1: 2,0k; 0207/7
R2: 1,3k; 0207/7
R3: 100K; 0207/7
REG104: REG103GA; SOT223-5
VCC/GND(3.3V), VCC/GND(5V): PINHD-1X3/90; 1X03/90

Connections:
GOUT: C1.2, R2.1, REG104.3 (GND), REG104.TAB (GND_TAB), VCC/GND(3.3V).2, VCC/GND(5V).2
unnamed: C1.1, R3.1, REG104.1 (IN), VCC/GND(5V).1
unnamed: C2.2, R1.1, R2.2, REG104.4 (NR)
unnamed: R3.2, REG104.5 (ENABLE)
VOUT: C2.1, R1.2, REG104.2 (OUT), VCC/GND(3.3V).1

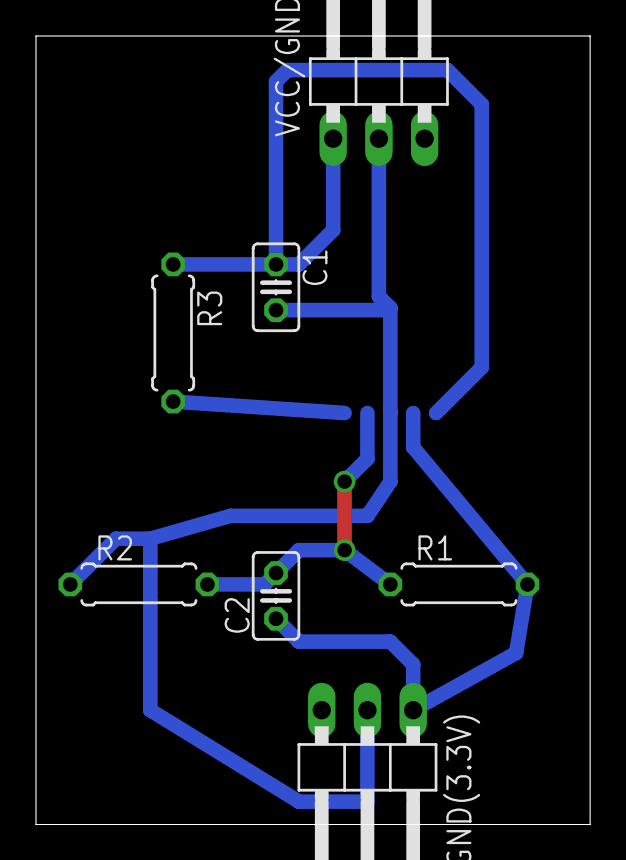
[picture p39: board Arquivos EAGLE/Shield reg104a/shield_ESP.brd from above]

Board: 2 copper layers, 30.8 x 43.8 mm, 8 parts (1 on the bottom side), 5 nets.

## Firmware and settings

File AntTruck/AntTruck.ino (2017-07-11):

#include <Servo.h>
#include <PID_v1.h> //Documentação: https://github.com/br3ttb/Arduino-PID-Library  & http://playground.arduino.cc/Code/PIDLibrary
#include <Thread.h> //Documentação: https://github.com/ivanseidel/ArduinoThread
#include <ThreadController.h> //Documentação: https://github.com/ivanseidel/ArduinoThread 
#define ENCODER_USE_INTERRUPTS//Precisa ser definido antes de Encoder.h
#include <Encoder.h> //Documentação: https://www.pjrc.com/teensy/td_libs_Encoder.html#optimize
#include <Navigator.h> //Documentação: https://github.com/solderspot/NavBot/blob/master/NavBot_v1/docs/Navigator.md
#include <PulseInZero.h>  //Documentação: https://gist.github.com/mikedotalmond/6044960
#include <PulseInOne.h> //Documentação: https://github.com/mikedotalmond/arduino-pulseInWithoutDelay
#include <math.h>
#include "Serialize.h"


//----------------------------------------------------------------------------//
//**************************** CONFIGURATIONS ********************************//
//----------------------------------------------------------------------------//
  // INTELLIGENT SPACE ATSP
  #define CFG_IS_ATSP             0

  #define CFG_MINBATERRY          9.5 // Minimum Battery Voltage
  #define CFG_MAXSPEED            250.0 // [mm/s]
  #define CFG_MAXTURNRATE         150.0 // [theta/s]
  #define CFG_FORCEFIELD_RADIUS   250 // Minimum US distance [mm]

  // Battery Monitoring
  #define CFG_RESISTOR_R1       18790
  #define CFG_RESISTOR_R2       12830

  // Navigator defines
  #define WHEEL_BASE      nvMM(191)
  #define WHEEL_DIAMETER  nvMM(60)
  #define TICKS_PER_REV   3591.84

  //Final Position Controller Defines
  #define FPC_CONVERGENCERADIUS 30.0  // Outside circle radius in mm for FPController
  #define FPC_MAXRo   50.0 // Distance in mm when the FPC starts to decrease speed
  #define FPC_Kw      0.3 // Angular Velocity Equation Constant 


  //Debugs:
  #define DEBUG_SETPIDINTERVAL  0     // PWM max
  #define DEBUG_ESP_FEEDBACK    1     // Usage of "Serial.print" 

  //Testes:
  #define TST_MOTORS      0 // Nominal voltage test
  #define TST_COLLECTDATA   0 // Used to collect motors data
  #define TST_ESPsendData   0 // Test sending variables to ESP

  const int TENSAO_NOMINAL_MOTOR = 6; // Motors nominal power suply
////////////////////////////////////////////////////////////////////////////////


//----------------------------------------------------------------------------//
//************************** OBJECTS DECLARATION *****************************//
//----------------------------------------------------------------------------//
  /* Variables that had to be declared at the top of the code */

  /**** FPC vars *****/
  Navigator navigator;
  nvPose nav_Pose;
  double nav_pos_x, nav_pos_y, nav_heading;
  double nav_velLinear, nav_velAngular;
  double Ro, alpha, betha, gamma;  // angles for navigation kinematics
  /*******************/

  //Support vars for RUNNING state:
  double RUNNING_x, RUNNING_y;
  // TANGENTIAL ESCAPE
  double virtual_x, virtual_y;
  //------------------------------

  // US Distances:
    uint16_t dist_US_Frente=0, dist_US_Direito=0, dist_US_Esquerdo=0;
  //--------------------------------------------------------------

  //Threads:
  ThreadController TC_ESP_SERIAL;
  Thread T_ESP_SERIAL;
////////////////////////////////////////////////////////////////////////////////


//----------------------------------------------------------------------------//
//************************* PINS, INPUTS, OUTPUTS ****************************//
//----------------------------------------------------------------------------//
  //PINs motores: 
  // May be inverted in case of wrong direction 
  #define motorDireita_IN1  6
  #define motorDireita_IN2  5
  #define motorEsquerda_IN3 9
  #define motorEsquerda_IN4 10
  //---------------------------------

  //PINs ultrassom:
  #define US_Frente_TrigPin 39
  //----------------------------------------------
  #define US_Direito_TrigPin 49
  //----------------------------------------------
  #define US_Esquerdo_TrigPin 29
  //--------US Interrupt
  const int US_EchoPin = 2; //pino de interrupção dos US
  //----// Pins US Servo:
  #define US_servo_TrigPin 4
  #define pin_Servo 8
  const int US_servo_EchoPin = 3; //pino de interrupção dos US servo
////////////////////////////////////////////////////////////////////////////////


//----------------------------------------------------------------------------//
//*********************** PID/FINAL POSITION CONTROLLER ************************
//----------------------------------------------------------------------------//

  // PID Variables:
  double  rPID_Setpoint,rPID_Input,rPID_Output,
  lPID_Setpoint,lPID_Input,lPID_Output;
  double  Kp= 0.55, Ki = 0.35, Kd=0.0;
  // double  Kp= 0.55, Ki = 0.006, Kd=0.0; // Constants for FPC
  //---------------------------------------------//
  double pid_max_PWM = 150; 
  //---------------------------------------------//

  //Objetos PIDs:
  PID PID_right(&rPID_Input, &rPID_Output, &rPID_Setpoint, Kp, Ki, Kd, DIRECT);
  PID PID_left(&lPID_Input, &lPID_Output, &lPID_Setpoint, Kp, Ki, Kd, DIRECT);


  //Methods:
  void set_PID_Intervals(){ //Altera intervalo de saida PID:
    pid_max_PWM = (255*(TENSAO_NOMINAL_MOTOR + 0.7))/calcula_V_Bateria(0);
                                             //+0.7->queda de tensao diodos

    PID_right.SetOutputLimits(-pid_max_PWM, pid_max_PWM);
    PID_left.SetOutputLimits(-pid_max_PWM, pid_max_PWM);
    
    //Debug:
    #if DEBUG_SETPIDINTERVAL
    Serial.println("*****Debug set_PID_Intervals():");
    Serial.print("Novo limite: ");
    Serial.println(pid_max_PWM);
    Serial.println(" ");
    Serial.println(" ");
    #endif
  }

  /**  Speed Saturation Function **
   ** Returns a Speed Scale for the Speed saturator
   *  Replaces tanh(Ro) **/ 
   double FPC_Saturator(double Ro){
    if (Ro > FPC_MAXRo){
      return 1;
    }
    else{
      return (Ro/FPC_MAXRo);
    }
  }
  //------------------------------------------------------------

  //Final Position Controller (FPC):
  void FPController(double fpos_x, double fpos_y){ //need to be called in every 'RUNNING' loop
    //Vars
    double fv, fw;
    
    //Calc Ro and alpha:
    double delta_y = fpos_y - nav_pos_y;
    double delta_x = fpos_x - nav_pos_x;
    Ro = sqrt( delta_y*delta_y + delta_x*delta_x );
      //x-axe forward , y-axe to the left:
      alpha = ( atan2(delta_y,delta_x) - nav_heading );

    //Calc v and w:
      fv = CFG_MAXSPEED*FPC_Saturator(Ro)*cos(alpha); // CFG_MAXSPEED*tanh(Ro)*cos(alpha)
      fw = FPC_Kw*alpha + fv*sin(alpha)/Ro; // fw = Kw*alpha + CFG_MAXSPEED*(tanh(Ro)/Ro)*sin(alpha)*cos(alpha)
      
      //Update new setpoints:
      driveRobot(fv,fw);
  }

  // PIDs Calculations:
  void computePID(){
    PID_right.Compute();
    PID_left.Compute();
  }
  //-------------------------------------------------------------

  //Thread para alterar os intervalos:
  Thread T_set_PID_Intervals;

  //Thread Controller:
  ThreadController TC_BATERIA;
////////////////////////////////////////////////////////////////////////////////

//----------------------------------------------------------------------------//
//************************ TANGENCIAL ESCAPE CONTROLLER ************************
//----------------------------------------------------------------------------//
  // Calc virtual target for Tangecial Escape Controler
  void calcVirtualTarget(){
    int8_t sign;  

    //Look for minimum distance:
      if( (dist_US_Frente<dist_US_Direito) && (dist_US_Frente<dist_US_Esquerdo)){
        betha = 0;
        sign = 1;
      }
      else if( (dist_US_Direito<dist_US_Frente) && (dist_US_Direito<dist_US_Esquerdo) ){
        betha = -(M_PI/4);
        sign = -1;   
      }
      else if( (dist_US_Esquerdo<dist_US_Frente) && (dist_US_Esquerdo<dist_US_Direito) ){
        betha = M_PI/4;
        sign = 1;
      }

    
    //Calc rotation angle 
    // gamma = (sign*(abs(betha)-M_PI/2)) - alpha; //FRODO
    gamma = (sign*(M_PI/2)) - (betha - alpha); // FABRICIO

    //Coordinates transformation
    // ->  Robot referential
    double theta = nav_heading; // Readable equations
    double robot_Xd = (cos(theta)*RUNNING_x) + (sin(theta)*RUNNING_y) - (cos(theta)*nav_pos_x)-(sin(theta)*nav_pos_y);
    double robot_Yd = -(sin(theta)*RUNNING_x) + (cos(theta)*RUNNING_y) + (sin(theta)*nav_pos_x)-(cos(theta)*nav_pos_y);

    // Calc Robot Virtual Destination
    // Rotate by the angle 'gamma' calculated:
    double robot_VirX = (cos(gamma)*robot_Xd) + (sin(gamma)*robot_Yd);
    double robot_VirY = -(sin(gamma)*robot_Xd) + (cos(gamma)*robot_Yd);

    //Calc Virtual Target:
    // Robot Reference -> World Reference
    virtual_x = cos(theta)*robot_VirX - sin(theta)*robot_VirY + nav_pos_x;
    virtual_y = sin(theta)*robot_VirX + cos(theta)*robot_VirY + nav_pos_y;
  }


////////////////////////////////////////////////////////////////////////////////


//----------------------------------------------------------------------------//
//************************ QUADRATURE ENCODER  *******************************//
//----------------------------------------------------------------------------//
  // Change these two numbers to the pins connected to your encoder.
  //   Best Performance: both pins have interrupt capability
  //   Good Performance: only the first pin has interrupt capability
  //   Low Performance:  neither pin has interrupt capability
  Encoder enc_Direita(20, 21);
  Encoder enc_Esquerda(19, 18);
  //   avoid using pins with LEDs attached

  ///////Variáveis de posição:
  double encDIR_Position  = 0, encDIR_lastPosition = 0, encDIR_lastTIME=0;
  double encESQ_Position  = 0, encESQ_lastPosition = 0, encESQ_lastTIME=0;
  /////////////////////////////////////////////////////////////////////////

  double calcVel_Direita(bool _debug){
    double _vel, tempoAtual;
    tempoAtual = millis();

  encDIR_Position = enc_Direita.read(); //leitura posição atual

  _vel = ((encDIR_Position - encDIR_lastPosition)/(tempoAtual - encDIR_lastTIME) )* 52.491105; // v = deltaS/deltaT
  encDIR_lastTIME = tempoAtual;
  encDIR_lastPosition = encDIR_Position;

  if(_debug){
    Serial.println("**** Debug Calculo Velocidade Direito *****");
    Serial.print("Tempo entre uma leitura e outra:  ");
    Serial.println(tempoAtual - encDIR_lastTIME);
    Serial.print("encDIR_lastPosition:  ");
    Serial.println(encDIR_lastPosition);
    Serial.print("Velocidade Direito:  ");
    Serial.println(_vel);
    Serial.println("*********************************************");
    Serial.println(" ");
  }

  return _vel;
  }

  double calcVel_Esquerda(bool _debug){
    double _vel, tempoAtual;
    tempoAtual = millis();

  encESQ_Position = enc_Esquerda.read(); //leitura posição atual

  _vel = ((encESQ_Position - encESQ_lastPosition)/(tempoAtual - encESQ_lastTIME) )* 52.491105; // v = deltaS/deltaT
  encESQ_lastTIME = tempoAtual;
  encESQ_lastPosition = encESQ_Position;

  if(_debug){
    Serial.println("**** Debug Calculo Velocidade Esquerdo *****");
    Serial.print("Tempo entre uma leitura e outra:  ");
    Serial.println(tempoAtual - encESQ_lastTIME);
    Serial.print("encESQ_lastPosition:  ");
    Serial.println(encESQ_lastPosition);
    Serial.print("Velocidade Esquerdo:  ");
    Serial.println(_vel);
    Serial.println("*********************************************");
    Serial.println(" ");
  }

  return _vel;
  }
////////////////////////////////////////////////////////////////////////////////


/*******************************************************************************
************************************ ODOMETRY **********************************
*******************************************************************************/

  double lticks=0, last_rticks=0, rticks=0, last_lticks=0;
  double t_rticks, t_lticks; //Total ticks


  void odometria(bool debug){
    // Current encoders counters:
    t_rticks = enc_Direita.read();
    t_lticks = enc_Esquerda.read();

    //Counter differencial:
    rticks = t_rticks - last_rticks;
    lticks = t_lticks - last_lticks;

    // Update Navigator parameters:
    navigator.UpdateTicks( lticks, rticks, millis() );

    // Update last encoders counters:
    last_rticks = t_rticks;
    last_lticks = t_lticks;
    //------------------------------------------------

    //Update PID inputs:
    rPID_Input = navigator.RightSpeed();
    lPID_Input = navigator.LeftSpeed();
    //-------------------------------------------------

    // Update Atual Position for the FPC: 
    nav_Pose = navigator.Pose();
    nav_pos_x = nav_Pose.position.x;
    nav_pos_y = nav_Pose.position.y;
    nav_heading = nav_Pose.heading;
    nav_velLinear = navigator.Speed(); //Debug only
    nav_velAngular = navigator.TurnRate(); //Debug only
    //-------------------------------------------

    if(debug){
      Serial.print("enc_Direita.read(): " );
      Serial.print(enc_Direita.read());
      Serial.print("\trticks: ");
      Serial.print(rticks);
      Serial.print("\tenc_Esquerda.read(): " );
      Serial.print(enc_Esquerda.read());
      Serial.print("\tlticks: " );
      Serial.println(lticks);
    }
  }
////////////////////////////////////////////////////////////////////////////////


/*******************************************************************************
******************************** MOVEMENT FUNCTIONS ****************************
*******************************************************************************/

  void driveRobot(double v, double w){ 
    //Saturation:
    // v = (v>CFG_MAXSPEED) ? CFG_MAXSPEED : v;
    // w = (w>CFG_MAXTURNRATE) ? CFG_MAXTURNRATE : w;

    //Inverse calculation of RifhtSpeed and LeftSpeed:
    rPID_Setpoint = (v + (w*WHEEL_BASE/2));
    lPID_Setpoint = (v - (w*WHEEL_BASE/2));
  }

  void motorHandler(){ //Must be called constantly

    //Set motors new values:
    if( (rPID_Output>=0) && (lPID_Output>=0) ){
      analogWrite(motorDireita_IN1, LOW);
      analogWrite(motorDireita_IN2, rPID_Output);
      analogWrite(motorEsquerda_IN3, lPID_Output);
      analogWrite(motorEsquerda_IN4, LOW);
    }
    else if( (rPID_Output<=0) && (lPID_Output>=0) ){
      analogWrite(motorDireita_IN1, abs(rPID_Output));
      analogWrite(motorDireita_IN2, LOW);
      analogWrite(motorEsquerda_IN3, lPID_Output);
      analogWrite(motorEsquerda_IN4, LOW);
    }
    else if( (rPID_Output>=0) && (lPID_Output<=0) ){
      analogWrite(motorDireita_IN1, LOW);
      analogWrite(motorDireita_IN2, rPID_Output);
      analogWrite(motorEsquerda_IN3, LOW);
      analogWrite(motorEsquerda_IN4, abs(lPID_Output));
    }
    else if( (rPID_Output<=0) && (lPID_Output<=0) ){
      analogWrite(motorDireita_IN1, abs(rPID_Output));
      analogWrite(motorDireita_IN2, LOW);
      analogWrite(motorEsquerda_IN3, LOW);
      analogWrite(motorEsquerda_IN4, abs(lPID_Output));
    }
  }

  void stopAll(){  
    analogWrite(motorDireita_IN1, LOW);
    analogWrite(motorDireita_IN2, LOW);
    analogWrite(motorEsquerda_IN3, LOW);
    analogWrite(motorEsquerda_IN4, LOW);    
  }
////////////////////////////////////////////////////////////////////////////////


/*******************************************************************************
*************************** ULTRASOUNDS VARS AND FUNCTIONS *********************
*******************************************************************************/

  //Constantes de Cálculos:
  const float SpeedOfSound      = 343.2; // ~speed of sound (m/s) in air, at 20°C         
  const float MicrosecondsPerMillimetre   = 1000.0 / SpeedOfSound; // microseconds per millimetre - sound travels 1 mm in ~2.9us
  const float  MicrosecondsToMillimetres  = (1.0 / MicrosecondsPerMillimetre);
  const float  MicrosecondsToMillimetres2 = MicrosecondsToMillimetres / 2.0; // beam travels the distance twice... so halve the time.
  //--------------------------------------------------------------------------

  //Variáveis de controle:
  uint8_t _swch = 1;
  boolean _done = true;
  //----------------------------------------------------------------------------

  //Threads:
  Thread T_USinterrupt_Read;
  //-------------------
  ThreadController TC_US;
  //-------------------------

  void us_Read() {
    if (_done){
      uint8_t trig_pin;

      switch(_swch){
        case 1:
        trig_pin = US_Frente_TrigPin;
        break;
        case 2:
        trig_pin = US_Direito_TrigPin;
        break;
        case 3:
        trig_pin = US_Esquerdo_TrigPin;
        break;
        default:
        _swch=1;
        break;
      }

      //seta o pino TRIG com pulso alto "HIGH" 
      digitalWrite(trig_pin, HIGH);  
      //delay de 10 microssegundos  
      delayMicroseconds(11);  
      //seta o pino TRIG com pulso baixo novamente  
      digitalWrite(trig_pin, LOW);

      //start listening out for the echo pulse on interrupt 0 (pino 2):
      PulseInZero::begin();

      _done = false;
    }
  }

  void us_PulseComplete(unsigned long duration){
    switch(_swch){
      case 1:
      dist_US_Frente = duration * MicrosecondsToMillimetres2;
      _swch = 2;
      break;
      case 2:
      dist_US_Direito = duration * MicrosecondsToMillimetres2;
      _swch = 3;
      break;
      case 3:
      dist_US_Esquerdo = duration * MicrosecondsToMillimetres2;
      _swch = 1;
      break;
    }
    _done = true;
  }
////////////////////////////////////////////////////////////////////////////////


/*******************************************************************************
********************************* SERVO ULTRASOUND *****************************
*******************************************************************************/
  //Servo
  Servo servoUS;

  //Threads:
  Thread T_USi_Servo_Read;

  //Variaveis:
  uint16_t dist_US_servo=0;
  //-----------------------------------------------------------

  // Funções de leitura do US:

  //Read:
  void us_servoRead() {
  //seta o pino TRIG com pulso alto "HIGH" 
  digitalWrite(US_servo_TrigPin, HIGH);  
  //delay de 10 microssegundos  
  delayMicroseconds(11);  
  //seta o pino TRIG com pulso baixo novamente  
  digitalWrite(US_servo_TrigPin, LOW);

  //start listening out for the echo pulse on interrupt 1 (pino 3):
  PulseInOne::begin();
  }
  //----------------------------------------------

  //Gatilho da interrupção:
  void us_servo_PulseComplete(unsigned long duration){
    dist_US_servo = MicrosecondsToMillimetres2 * duration;
  }
  //

  // Funções de Movimento - Servo:
  void servo_varrer(){
    byte i;

    if (i < 90){
      for(i; i>=180; i++){
        servoUS.write(i);
        delay(50);
      }
    }
    else{      
      for(i; i<=0; i--){
        servoUS.write(i);
        delay(50);
      }
    }
  }
////////////////////////////////////////////////////////////////////////////////


/*******************************************************************************
********************************* BATTERY MONITORING ***************************
*******************************************************************************/

  //Valor dos resistores (Divisor de tensão):
  const int resistor_R1 = CFG_RESISTOR_R1, resistor_R2 = CFG_RESISTOR_R2; 
  const int pin_AnalogDivisor = A0;
  /////////////////////////////////////////////

  //Encontrar a tensão da bateria:
  double calcula_V_Bateria(bool _debug){
    double tensao_Vo[10], tensao_Vi[10], tensao_Vin=0;

    for(int i=0; i<10; i++){
      tensao_Vo[i] = (analogRead(pin_AnalogDivisor)*5.00)/1023.00;
    tensao_Vi[i] = (tensao_Vo[i]*(resistor_R1+resistor_R2))/resistor_R2; //divisor de tensão.
    tensao_Vin += tensao_Vi[i];
    }

    tensao_Vin = (tensao_Vin / 10.0);

    //Debug:
    if(_debug){
      Serial.println("*****Debug calcula_V_Bateria():");
      Serial.println(">>tensao_Vo: ");
      for(int i=0; i<10; i++){
        Serial.println(tensao_Vo[i]);
      }
      Serial.println(">>tensao_Vi: ");
      for(int i=0; i<10; i++){
        Serial.println(tensao_Vi[i]);
      }
      Serial.print(">>tensao_Vin: ");
      Serial.println(tensao_Vin);
      Serial.println(" ");
      Serial.println(" ");  
    }

    return tensao_Vin - 0.15; //(0.15 margem de erro)
  }

  Thread T_alertaBateria;
  //Tensão abaixo do limite minimo:
  boolean warn=false;
  void alertaBateria(){
    if( calcula_V_Bateria(0) > CFG_MINBATERRY ){
      warn=false;
      }else{
        warn=true;
      }
  //Desabilita Robô caso tensão baixa:
    while (warn){ //loop infinito
      changeState("stopAll");
      stopAll();
      
      servoUS.write(90);
      delay(200);
      servoUS.write(180);
      delay(800);
      servoUS.write(0);
      delay(800);
      servoUS.write(90);

      Serial.println("=======> BATERIA FRACA!! <=========");
      delay(3000);
    }
  }
////////////////////////////////////////////////////////////////////////////////
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
void loop() {
  TC_BATERIA.run(); // Controls battery monitoring functions
  TC_US.run(); // Controls ultrasound sensors readings
  TC_ESP_SERIAL.run(); // Sends variables buffer to the ESP8266 every 500ms
  computePID(); // Calculates PID's parameters
  odometria(0); // Calculates position, velocity, orientation, etc
//-------------------//
  stateController();    // States machine
//-------------------//
  ESP8266_feedback();   // Receives commands coming from the ESP8266 
//-------------------//

//Debugs:
  // debug_Odometria();
  // debug_PID();
  // debug_Encoder();
  // debug_Ultrassom();
//------------------------
}

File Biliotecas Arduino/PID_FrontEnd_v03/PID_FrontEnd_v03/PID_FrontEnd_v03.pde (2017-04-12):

/********************************************************
 * Arduino PID Tuning Front-End,  Version 0.3
 * by Brett Beauregard
 * License: Creative-Commons Attribution Share-Alike
 * April 2011
 *
 * This application is designed to interface with an
 * arduino running the PID Library.  From this Control
 * Panel you can observe & adjust PID performance in 
 * real time
 *
 * The ControlP5 library is required to run this sketch.
 * files and install instructions can be found at
 * http://www.sojamo.de/libraries/controlP5/
 * 
 ********************************************************/

import java.nio.ByteBuffer;
import processing.serial.*;
import controlP5.*;

/***********************************************
 * User spcification section
 **********************************************/
int windowWidth = 900;      // set the size of the 
int windowHeight = 600;     // form

float InScaleMin = 0;       // set the Y-Axis Min
float InScaleMax = 1024;    // and Max for both
float OutScaleMin = 0;      // the top and 
float OutScaleMax = 255;    // bottom trends


int windowSpan = 300000;    // number of mS into the past you want to display
int refreshRate = 100;      // how often you want the graph to be reDrawn;

//float displayFactor = 1; //display Time as Milliseconds
//float displayFactor = 1000; //display Time as Seconds
float displayFactor = 60000; //display Time as Minutes

String outputFileName = ""; // if you'd like to output data to 
// a file, specify the path here

/***********************************************
 * end user spec
 **********************************************/

int nextRefresh;
int arrayLength = windowSpan / refreshRate+1;
int[] InputData = new int[arrayLength];     //we might not need them this big, but
int[] SetpointData = new int[arrayLength];  // this is worst case
int[] OutputData = new int[arrayLength];


float inputTop = 25;
float inputHeight = (windowHeight-70)*2/3;
float outputTop = inputHeight+50;
float outputHeight = (windowHeight-70)*1/3;

float ioLeft = 150, ioWidth = windowWidth-ioLeft-50;
float ioRight = ioLeft+ioWidth;
float pointWidth= (ioWidth)/float(arrayLength-1);

int vertCount = 10;

int nPoints = 0;

float Input, Setpoint, Output;

boolean madeContact =false;
boolean justSent = true;

Serial myPort;

ControlP5 controlP5;
controlP5.Button AMButton, DRButton;
controlP5.Textlabel AMLabel, AMCurrent, InLabel, 
OutLabel, SPLabel, PLabel, 
ILabel, DLabel,DRLabel, DRCurrent;
controlP5.Textfield SPField, InField, OutField, 
PField, IField, DField;

PrintWriter output;
PFont AxisFont, TitleFont; 

void setup()
{
  frameRate(30);
  size(windowWidth , windowHeight);

  println(Serial.list());                                           // * Initialize Serial
  myPort = new Serial(this, Serial.list()[1], 9600);                //   Communication with
  myPort.bufferUntil(10);                                           //   the Arduino

  controlP5 = new ControlP5(this);                                  // * Initialize the various
  SPField= controlP5.addTextfield("Setpoint",10,100,60,20);         //   Buttons, Labels, and
  InField = controlP5.addTextfield("Input",10,150,60,20);           //   Text Fields we'll be
  OutField = controlP5.addTextfield("Output",10,200,60,20);         //   using
  PField = controlP5.addTextfield("Kp (Proportional)",10,275,60,20);          //
  IField = controlP5.addTextfield("Ki (Integral)",10,325,60,20);          //
  DField = controlP5.addTextfield("Kd (Derivative)",10,375,60,20);          //
  AMButton = controlP5.addButton("Toggle_AM",0.0,10,50,60,20);      //
  AMLabel = controlP5.addTextlabel("AM","Manual",12,72);            //
  AMCurrent = controlP5.addTextlabel("AMCurrent","Manual",80,65);   //
  controlP5.addButton("Send_To_Arduino",0.0,10,475,120,20);         //
  SPLabel=controlP5.addTextlabel("SP","3",80,103);                  //
  InLabel=controlP5.addTextlabel("In","1",80,153);                  //
  OutLabel=controlP5.addTextlabel("Out","2",80,203);                //
  PLabel=controlP5.addTextlabel("P","4",80,278);                    //
  ILabel=controlP5.addTextlabel("I","5",80,328);                    //
  DLabel=controlP5.addTextlabel("D","6",80,378);                    //
  DRButton = controlP5.addButton("Toggle_DR",0.0,10,425,60,20);      //
  DRLabel = controlP5.addTextlabel("DR","Direct",12,447);            //
  DRCurrent = controlP5.addTextlabel("DRCurrent","Direct",80,440);   //

  AxisFont = loadFont("axis.vlw");
  TitleFont = loadFont("Titles.vlw");
 
  nextRefresh=millis();
  if (outputFileName!="") output = createWriter(outputFileName);
}

void draw()
{
  background(200);
  drawGraph();
  drawButtonArea();
}
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

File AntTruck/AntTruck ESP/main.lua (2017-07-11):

-- main.lua --

dofile('mqtt_config.lua')
-- dofile('URL_decode.lua') --old
-- dofile('html_codes.lua') --old


--SERVER--

local unescape = function (s)
s = string.gsub(s, "+", " ")
s = string.gsub(s, "%%(%x%x)", function (h)
 return string.char(tonumber(h, 16))
 end)
return s
end


-- Inicia http server
srv=nil
collectgarbage()
srv=net.createServer(net.TCP)
srv:listen(80,function(conn)
   conn:on("receive", function(client,request)
     local buf = ""
     local _, _, method, path, vars = string.find(request, "([A-Z]+) (.+)?(.+) HTTP");
     if(method == nil)then
       _, _, method, path = string.find(request, "([A-Z]+) (.+) HTTP")
     end
     local _GET = {}
     if (vars ~= nil)then
       for k, v in string.gmatch(vars, "(%w+)=([^%&]+)&*") do
         _GET[k] = unescape(v)
       end
     end
     
     if (_GET.psw ~= nil and _GET.ap ~= nil) then
      client:send("Saving data..")
      file.open("config.lua", "w+")
      file.writeline('ssid = "' .. _GET.ap .. '"')
      file.writeline('password = "' .. _GET.psw .. '"')
      file.writeline('bip = "' .. _GET.bip .. '"')
      file.writeline('bport = "' .. _GET.bport .. '"')
      file.writeline('intent = "' .. _GET.intent .. '"'..' or "DEFAULT"')
      file.close()
      node.compile("config.lua")
      client:send(buf)
      node.restart()
    end
    
    buf = "<html><body>"
    buf = buf .. "<h3>Configure WiFi</h3><br>"
    buf = buf .. "<form method='get' action='http://" .. ip .."'>"
    buf = buf .. "Enter wifi SSID: <input type='text' name='ap'></input><br>"
    buf = buf .. "Enter wifi password: <input type='password' name='psw'></input><br>"
    buf = buf .. "Enter MQTT Broker IP: <input type='text' name='bip'></input><br>"
    buf = buf .. "Enter MQTT Broker PORT: <input type='text' name='bport' value='1883'></input><br>"
    buf = buf .. "Enter intent (Options: DEFAULT, IS): <input type='text' name='intent' value='DEFAULT'></input><br>"
    buf = buf .. "<br><button type='submit'>Save</button>"               
    buf = buf .. "</form></body></html>"
    client:send(buf)
    client:close()
    collectgarbage()
    end)
        ------------------
	conn:on("sent",function(conn) conn:close() end)
end)
---------------------------------------------------

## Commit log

2016-11-09 Including SuperTruck codes and Eagle files
    [Mega_Shield-v13.brd, Mega_Shield-v13.sch, Mega_Shield-v3.brd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]
2016-11-09 Including all other files
    [Base_Arduino.SLDPRT, Chave_v1.SLDPRT, Chave_v1.STL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]
2017-01-10 Changes in Eagle boards and Arduino libraries
    [Mega_Shield-v13.brd, Mega_Shield-v13.sch, Mega_Shield-v3.brd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]
2017-01-12 3D Parts Dimensions Added.
    [Base_Arduino.SLDPRT, Chave_v1.SLDPRT, Chave_v1.STL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]
2017-03-10 fixed bugs
    [Montagem1 - Suporte_ESP8266_v4 - P1-1.STL, Montagem1 - Suporte_ESP8266_v4 - P2-1.STL, Montagem1.SLDASM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]
2017-03-22 Changed uart setup.
2017-03-22 Added setPID by mqtt method
    [suporte_padrao.SLDPRT, suporte_padrao.STL]
2017-07-11 Send vars to Arduino period changed.

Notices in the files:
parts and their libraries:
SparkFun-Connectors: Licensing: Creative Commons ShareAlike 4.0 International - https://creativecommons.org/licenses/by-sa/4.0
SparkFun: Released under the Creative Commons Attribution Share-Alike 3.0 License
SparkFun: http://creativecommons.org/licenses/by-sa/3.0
